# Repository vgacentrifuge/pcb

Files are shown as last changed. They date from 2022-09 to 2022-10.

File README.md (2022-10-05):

# VGA mixer PCB design
This repository contains the research and design work that went into the PCB
for our VGA mixer project in TDT4295 - computer project at NTNU, autumn 2022.

## Initial feasibility study
The [pdf](InitialFeasibilityStudy.pdf) contains the first research, before
the capabilities and requirements were fully fleshed out. In this repo,
we are working on the actual design.

## Project features
The VGA mixer is a device that takes two VGA inputs,
called "background" and "foreground", and outputs a single VGA video stream.

It should support the SVGA resolution 800x600 @ 60Hz and 16-bit color depth.
The colors are stored as (5,6,5)-bit RGB values internally.

On the board there are several buttons and an LCD screen,
allowing you to pick between different **modes**:
 - Showing only the foreground
 - Showing only the background
 - Overlaying with chroma keying appied to the foreground
 - Showing the foreground at 25%, 50% or 75% transparancy
 - Adding the colors (double exposure)

In addition to modes, the foreground can also be **scaled** and **translated**:
 - A button lets you pick between 100%, 50% and 25% size of the foreground.
 - Directional buttons allow you to move the foreground around

Finally, the foreground video input can be replaced by a still image loaded
from an SD card. Chroma keying can still be applied, to create borders or overlays.

TODO: Should we be able to save images, or is having a bank of overlays enough?

The LCD allows the user to orchestrate the modes and options to create quick
transitions, and saving states.

## Implementation overview
Both the background and foreground VGA signals get converted into digial pixel color values.
ADC chips do the conversion, and an FPGA reads the digital data.

The background video signal is never scaled or translated, and can be sent
almost directly out to the output DAC.
The output signal is just a few pixels behind the background.

The foreground gets buffered, either in SRAM or the FPGA's internal block RAM.
When the background signal is passing through the FPGA, it knows which pixel it is processing.
By checking its settings, it will know if and where the foreground framebuffer should be sampled.
Translations and scaling affect how the foreground overlays the background.

Scaling is done by doubling or quadrupling the current pixel coordinate (left shifting).
Translations are done by adding offsets. If the resulting pixel position
is still within the framebuffer bounds, it gets sampled.

Chroma key is handled by looking at the color chanels.
Transparancy is done by averaging the foreground and background layers.
To get 25% foreground, pixel = (fg+(fg<<1) + bg) >> 2, or something similar.
We don't want to do actual division.

User input is handled by an MCU, which is connected to the FPGA via SPI.
The MCU also handles the VGA input data pins, to communicate to our video sources
what resolution we support.

The SD card is also connected to the MCU over another SPI.
We use FAT32 formatted SD-cards, allowing the user to prepare overlays on their computer, saved as bmp.
See [this project here](https://create.arduino.cc/projecthub/SurtrTech/display-bmp-pictures-from-sd-card-on-tft-lcd-shield-f3074c).
The MCU does all file system work and image decoding. The LCD can be used to pick images by file name.
When selected, the foreground input gets ignored, and the FPGA fills the framebuffer with the image instead, sent over SPI.

In general, the MCU takes user input and uses SPI to send a state struct to the FPGA.
This means timed transitions, and switching between saved states, can be orchestrated from there.
Note that the MCU doesn't have enough RAM to store even a single frame.

## Components
This section contains the components we will need to place on the PCB.

### FPGA
We are working with the Artix-7 series, see the [Series Overview](https://docs.xilinx.com/v/u/en-US/ds180_7Series_Overview).

#### Dev-board
The [ARTY A7 development board](https://digilent.com/reference/programmable-logic/arty-a7/reference-manual) has an **ARTIX-7 XC7A35T** which has
 - 33280 logic cells
 - 50 blocks of 36Kib dual port block ram = 1 800Kib
 - 5 clock management tiles (CMTs), each with a phase-locked loop and mixed-mode clock manager
 - Programmable over JTAG or Quad-SPI Flash
 
The dev-board itself contains:
 - 256MB DDR3L with a 16-bit bus @ 667MHz
 - 16MB Quad-SPI Flash
 
#### On PCB
On the PCB we will use the **ARTIX-7 XC7A100T** in FTG256 package, which has already been procured.
 - 4,860 Kib of dual port block ram
 
See the data sheet for it [here](https://docs.xilinx.com/v/u/en-US/ds181_Artix_7_Data_Sheet),
and remember the user guides listed in the pcb lecture.

#### Voltages
The FPGA requires:
 - 1.0V (Vccint & Vccbram)
 - 1.8V (Vccaux)
 - 3.3V (Vcco) The standard signal voltage we use for I/O banks.

They must become ready in order, Vccint and Vccbram can rise together. 
For one bank, Vcco=1.8V, and the datasheet said it's fine to rise it together with Vccaux.

#### Required FPGA support components
In the datasheet they define that certain sets of **decoupling capacitors** should be connected to certain pins.
This is already included in the example schematic from the lecture.
Try to get them close to the pins on the actual PCB.

We also need a **configuration flash chip** on the board,
to program the FPGA on startup. See UG908 Appendix C.
We picked the one from the pcb lecture: [S25FL127SABMFV101](https://www.digikey.no/en/products/detail/cypress-semiconductor-corp/S25FL127SABMFV101/5788556).

#### FPGA's own clock signal
To not completly rely on the MCU's clockout,
The [arty schematic](https://digilent.com/reference/_media/arty:arty_sch.pdf) has and
[ASEM1-100.000MHZ-LC-T](https://no.mouser.com/ProductDetail/ABRACON/ASEM1-100.000MHZ-LC-T?qs=3KFUwL3kAg3Sbz4Re5NI5g%3D%3D), but it's not in stock.

We use the [EC2620TTS-100.000MTR](https://no.mouser.com/ProductDetail/Ecliptek-Abracon/EC2620TTS-100.000M-TR?qs=ZQxglWs2YhXyVb5B6v%252BGOw%3D%3D).

I checked the Xilinx Clocking Wizard, both MMCM and PLL will happily turn 100MHz into 160MHz.

#### Debug connector
The Debug connector from the lecture looks like the **14-pin F JTAG ILA connector**.
See [this website](https://developer.arm.com/documentation/100765/0000/Signal-descriptions/Debug-connectors/14-pin-F-JTAG-ILA-connector).
The pitch is 2mm, yes you read that right.
The component, through hole, can be found here:
[0878311411](https://www.digikey.no/en/products/detail/molex/0878311411/3313107).

See the example setup from the lecture (remember 2x 10k pullups).
However, this website says that pin 6 (TCK) is pulled down on their board,
**why is ours pulled up?** 

### SRAM
We need to calculate the required SRAM size.
With an 800x600=480 000 pixel grid, 16 bit color depth, it makes sense to
use a 512K x 16 bit SRAM. We do however also want to make the SRAM easy to address.

800 pixels of X-coordinate rounds up to 10 bits.
600 pixels of Y-coordinate also rounds up to 10 bits.
A 20 bit address means 2^20 = 1M x 16bit SRAM.

This size would also allow us to support 1024x768 (XGA),
but speed is a bigger issue. XGA has a pixel clock of 15.3ns / pixel.

To get good speed, we have looked at the syncronous 1M x 18b SRAM [CY7C1372KV33-200AXC](https://www.digikey.no/en/products/detail/cypress-semiconductor-corp/CY7C1372KV33-200AXC/5982740)
which supposedly costs 94kr per chip. It takes 3.3V.
With pipelining, the access time becomes 3ns,
with each operation delayed for two cycles.

The number of pins needed becomes:
 - 20 address pins
 - 18 data pins
 - write enable
 - clock
 - chip select
 - output enable

We use chip select to deselect, which when we don't need access.
The deselect is pipelined as well, allowing us to mix it into the operations.

We want to connect output enable to be sure that we never try to
write to th data line while it is being driven.
If we do everything perfectly, The data line is automatically tri-stated by writes,
but we want to be safe.

The rest, like output enable, clock enable, byte enable, advance etc. can all be pulled by the pcb.
This SRAM package does not expose JTAG pins.

### MCU
Available in the lab is the EFM32GG990F1024-BGA112
 - ARM Cortex M3
 - Flash: 1024kB
 - RAM: 128kB
 - USB support
 - ADC: 8 channels, 12 bit
 - DAC: 2 channels, 12 bit
 - SPI: 3
 - I2C: 2
 - GPIO: 87
 - 112 pin BGA package
 
For PCB considerations, see [SiLabs EFM32 AN0002](https://www.silabs.com/documents/public/application-notes/an0002.0-efm32-ezr32-series-0-hardware-design-considerations.pdf).
It includes decoupling capacitors. See Figure 3.1. EFM32 Series 0 Standard Decoupling Example.
Also add the 1 Ohm resistor from Figure 3.3.

#### MCU Debug connector

In the PCB lecture, they use the 2.54mm pitch legacy JTAG.
The debug conenctor is 20-pin header, shown in section 4 of AN0002.

Since we have a gecko with the modern connector, we can use the
modern [Cortex Debug+ETM Connector](https://documentation-service.arm.com/static/5fce6c49e167456a35b36af1).
It has 1.27mm pitch, we pick this through-hole one: [3220-20-0100-00](https://www.digikey.no/en/products/detail/cnc-tech/3220-20-0100-00/3883663).

#### MCU Clock circuit
By using an external crystal, as recommended, we can run the MCU at 48MHz.

<!--
This is simply buying a crystal oscillator.
The [FO7HSCDE48.0-T1](https://www.digikey.no/no/products/detail/fox-electronics/FO7HSCDE48-0-T1/12160237)
is 48MHz, SMD, and with 5mm and 2.5mm between the 4 pins, which at least isn't the smallest oscillator.
The datasheet also has recommended solder pad distance of at least 2.2 mm. Seems doable.
-->

The first chip we bought was in fact not a crystal, but an oscialltor chip using a crystal insternally.
We buy another one instead, see the schematic.

The AN0002 EFM32 hardware design considerations also mentions two capacitors.
The lecture uses 2x 12pF.

The FPGA can take the **clock out** signal from the EMF32GG as a clock input, and use phase-locked loops
to internally run faster clocks at rational multiples of the input.
We should also have a clock circuit on the FPGA side, so that we have two options.

### Connections
We use SPI between MCU and FPGA, and between MCU and SD-card. They can be fully independent.
For our SPI communication, the lecture tells us to add extra wires between the MCU and PCB for safety.

[I2C](https://en.wikipedia.org/wiki/I%C2%B2C) is "open drain", which means we must use pull-up resistors on the lines.
Calculations can be found in this [EFM32GG application note](https://www.silabs.com/documents/public/application-notes/AN0011.pdf).

We use I2C for the LCD, and I2C for the ADCs.
They both seem to like 400kHz, which means a 2kOhm resistor is common.
They both also want to be pulled up to 3.3V.

Between the boards, if we do make two PCBs, we want to connect them.
We can buy e.g. 2 of the 2x8 pin vertical male header per board [3020-16-0200-00](https://www.digikey.no/en/products/detail/cnc-tech/3020-16-0200-00/3441735).
And 2 of the female as well [PPPC082LJBN-RC](https://www.digikey.no/en/products/detail/sullins-connector-solutions/PPPC082LJBN-RC/776019).
These are both through-hole.

### Splitting the MCU and FPGA
We have considered splitting the PCB in half, to separate the MCU from the FPGA.
In practice we will probably not create two PCBs,
since clock lines shouldn't go through pins,
but it would be great to have a PCB that can be used
without the MCU physically on the board.

With SPI, we control the speed ourselves, so we can tune it down until it is stable,
depending on how the wiring is.

The SPI between the MCU and FPGA should have room to solder on a pin header.
The SPI clock is slower than the 48MHz clock-out from the MCU,
which should **not** have a pin header.
We also give the FPGA its own oscillator, to not depend on the MCU clock out.

The SPI lane for the SD card can also have holes for soldering on a pin header if desired.
The I2C buses for the ADCs and LCD screen should have pins,
and the keyboard matrix should have them.

### Power circuit
We base it on the PCB lecture. We need to power up the 1.0V, 1.8V and 3.3V in order.
The MCU and SD card use 3.3V, so does the SRAM.
The ADC uses 1.9V, and HSYNC and VSYNC must be level switched to / from 5V.

**Remember the jumpers** between the power circuit and rest of the board.
We buy a 2x5 male 2.54mm pin header [3020-10-0300-00](https://www.digikey.no/en/products/detail/cnc-tech/3020-10-0300-00/3441727), and
the 2x5 female jumper shunt, [69145-210LF](https://www.digikey.no/en/products/detail/amphenol-cs-fci/69145-210LF/1528094), with 3A rating per pin.

### SD-card & SD-card slot
We want a slot to be able to move the SD-card to and from a computer.
When connected, the MCU communicates via SPI to the card.
In addition to the 4 SPI pins, The SD-card takes a 3.3V VDD and ground.

See for instance [this website](https://www.electroniccircuitsdesign.com/pinout/sd-microsd-card-pinout.html) for pinout on the physical SD and microSD cards.

Note that [this SO-post](https://electronics.stackexchange.com/questions/496357/sd-card-via-spi-pull-up-resistors-or-dedicated-ic)
talks about pull-up resistors on all the data pins, we can do that too.

People seem to disagree, but hooking up a 10k Ohm resistor to each of DAT0-DAT3 and CMD seems good.
Also a 0.1 uF decoupling capacitor between Vcc and GND.

To easily solder, we can buy the [10067847-001RLF](https://www.digikey.no/no/products/detail/amphenol-cs-fci/10067847-001RLF/2283478).
It is full size SD, with solder pins visible

We should buy an SD card as well, the 512MB microSD [5252](https://www.digikey.no/en/products/detail/adafruit-industries-llc/5252/15841478) is cheap,
so buy at least one.

### LCD text output
A cheap 2 row x 16 char width LCD screen is [DFR0555](https://www.digikey.no/no/products/detail/dfrobot/DFR0555/9356340).
It is controlled over I2C.
8-bit address for LCD: 0x7C = 0b 0111 110X
8-bit address for backlight: 0xC0 = 0b 1100 000X
At 87mm x 32mm total, it is quite small. Each char is 2.96mm x 5.56mm.
Mouser doesn't have anything cheaper using I2C, so it's probably a good option.

### Input panel
We need to design a button layout that fits our functionality,
but also allows us to experiment after the PCB design is finalized.

We can use an off the shelf keyboard matrix, and re-label the keys.
Mouser stocks 81 of the 4x4 [3844](https://no.mouser.com/ProductDetail/Adafruit/3844?qs=qSfuJ%252Bfl%2Fd6WS5%252BJGim1hw%3D%3D).

### VGA ports
We need the physical VGA ports, as well as supporting components.
The speed we target is [SVGA 800x600@60Hz](http://tinyvga.com/vga-timing/800x600@60Hz).

The VGA connector itself is [described here](http://www.hardwarebook.info/VGA).
For VGA output we only really need to connect 5 pins, plus ground:
 - red, green, blue color (analog 0-0.7V, 75 Ohm)
 - horizontal sync, vertical sync (5V). See timing chart.

Note: While we are in the "porch" and sync pulse areas of the signal, the color values must all be 0V.
See for example the 2nd [Ben Eater VGA video](https://www.youtube.com/watch?v=uqY3FMuMuRo).

We also might want to connect the 3 DDC2B ports, in case we want to read info about the output monitor.
See the following sections about DAC and VGA Display Data Channel.

For inputs, we need to read those 5 signals, including the analog color signals (using ADCs).
We should also let the video sources get info about our board over I2C. See next sections.

As for the physical VGA ports, there is [L77HDE15SD1CH4FVGA](https://www.digikey.no/no/products/detail/amphenol-icc-commercial-products/L77HDE15SD1CH4FVGA/4888525) on digikey at 15kr a pop. Is has through-hole pins. Buy 9, 3 per PCB.

#### VGA Display Data Channel
The [DDC2B](https://en.wikipedia.org/wiki/Display_Data_Channel#DDC2) standard is an I2C protocol to communicate information about the "monitor" to the video source.

For the output port, we can connect the DDC pins to one of the MCU's I2C ports,
in case we want to read info about the screen.
NOTE: The I2C lines are open drain, and expect to be pulled up to 5V.
We will need a level shifter for the MCU to be able to use the I2C port.

##### VGA DDC level switches
The VGA standard expects 5V I2C over the SDA and SCL lines.
Both when we are slave and master, we want to support this.
Since all other I2C components use 3.3V, we level switch.

[This guide](https://cdn-shop.adafruit.com/datasheets/an97055.pdf)
shows how a single N-channel MOSFET does the trick.
We buy 2 per DDC I2C, 6 per board.
We pick the one they mention that is easiest to solder: [BSN20](https://www.digikey.no/en/products/detail/diodes-incorporated/BSN20-7/2756034).

<!--
For the three DDC channels, we can use one of
[771-LSF0102DCH](https://no.mouser.com/ProductDetail/Nexperia/LSF0102DCH?qs=zW32dvEIR3vhhHCS5E8Gjg%3D%3D)
for each.

If you are curious how open-drain interfaces, like I2C, work through it,
[this datasheet](https://www.ti.com/lit/ds/symlink/lsf0102.pdf?ts=1663455770501)
for a similar device has an example in section 9.2.
-->

#### VGA HSYNC VSYNC Level shifters
They come in at 5V, but must be 3.3V into the ADC.
Same applies to the output VGA, but the other way.
We don't use the DAC's HSYNC and VSYNC ports,
instead letting the FPGA control it.
It would be nice to support 1.8V input, since the rest of video out is at 1.8V.

For each ADC, and for the output, buy one
[771-LSF0102DCH](https://www.digikey.no/no/products/detail/nexperia-usa-inc/LSF0102DCH/13574967).

##### Input VGA ports: I2C EEPROMs
On our VGA inputs, we should respond to I2C read commands, to return 128-256 bytes of read only [Extended Display Identification Data](https://en.wikipedia.org/wiki/Extended_Display_Identification_Data).
See [this page](http://www.hardwarebook.info/VGA_(VESA_DDC)) for specifications.
The VGA DDC uses three pins: I2C data, I2C clock, and DC +5V delivered by the video source.
Our board must respond to the 7-bit I²C address 50h (also known as A0h and A1h in 8-bit).

To save having to use our MCU from needing to be a slave over the VGA ports, we can buy dirt cheep I2C EEPROMSs.
For instance [M24C02-WMN6TP](https://www.digikey.no/no/products/detail/stmicroelectronics/M24C02-WMN6TP/1663568),
in stock at Digikey.no, at 1,7kr a piece. They work at 2.5V - 5.5V, and we use one per VGA input = 6 for 3 boards.

Note: The EEPROMs technically support running on 5V,
and the VGA port has 5V supplied by the graphics card.
The reason we don't want to use it is that the graphics card
expects us to draw < 1mA when the monitor is on.

In DDC, the I2C master will try to read from address 0xA1 = 0b1010 0001.
This is perfect! The EEPROM listens for address 0b1010 XXXX, where
we configure the first 3 X's ourselves. The last bit is 1 for read and 0 for write.

##### I2C EEPROM support components
 - Vcc should be decoupled "usually of the order of 10 nF to 100 nF, close to the Vcc/Vss pins".
 - E0, E1 and E2 should be connected to ground, to listen to the correct address.
 
 - We should create a jumper thing to let the MCU be the programmer, if we ever need to change the EEPROM.
 - It should have 5 pins:
   - Vcc (3.3V)
   - Vss
   - SCL
   - SDA
   - Write enable (just connect to Vss to enable writing)
 
 Opposite to it there should be the same 5 pins comming from one of the MCU's I2C buses,
 e.g. the one used to configure the ADCs.
 
 To make the connector easy, we can use a 3x5 pin header, and have the MCU connected
 to the middle row, and jump either to the left or right.
 See [TSW-105-07-F-T](https://www.digikey.no/en/products/detail/samtec-inc/TSW-105-07-F-T/6692070).

#### Input VGA ADCs
The analog color inputs of each VGA input needs to become digital 6 or 5 bit values.
We can use ADCs with more bit depth than this, and then ignore the least significant bits.

The video ADC we looked at is the 3 channel x 10bit TI [TVP7002PZPR](https://no.mouser.com/ProductDetail/Texas-Instruments/TVP7002PZPR?qs=0OHPnBYoB%2FnBqXV%2Fq5aVXw%3D%3D)

It is configurable over I2C, things like gain, clamp and offset. Also programmable subpixel positioning.
It also has a PLL on the HSYNC, allowing it to generate a pixel clock for the FPGA VGA inputs.
The 40MHz on SVGA is well within the 12-165MHz range.

So: **we need to connect the ADCs to the MCU, to program them**.
Luckily, the chips have one bit of customizable address, so the options are:
 - 0xB8 = 0b10111000
 - 0xBA = 0b10111010
Remember that the last bit is 1 for read and 0 for write.
Notably, neither of these addresses collide with the 0xA0/0xA1 of the VGA DDC,
but you have to remember voltages.

The ADC needs 3.3V and **1.9V**!

The I/O is however 3.3V, so we can connect it to a "normal" FPGA bank.

But: VGA HSYNC and VSYNC are 5V signals. We can **not** pass those into the ADC!
See the HSYNC VSYNC Level shifter section above.

##### ADC support components
See the example setup in the datasheets.

- 1x (=2x) ADC support
     - 3x (=6x) Sync-on-green input disable: 1nF capacitor
     - 7x (=14x) 10nF capacitors for unused analog input
     - 1x (=2x) PLL pump
       - 1x (=2x) Resistor 1.5kOhm
       - 1x (=2x) Capacitor 4.7nF
       - 1x (=2x) Capacitor 0.1uF
   - 1x (=2x) I2C address choice: Resistor 2.2kOhm
   - 3x (=6x) Color inputs
     - 1x (=6x) 75 Ohm resistors
     - 1x (=6x) 0.1 uF capacitors
   - 1x (=2x) VSYNC parallel 1nF capacitor
   - even more stuff, just look at the suggested schematic

#### Output VGA DAC
When outputing analog color data, we don't want to use resistors, as they take space,
and the FPGA outputs are not the best at delivering DC current.

A nice DAC that Mouser stocks is  [THS8136IPHP](https://no.mouser.com/ProductDetail/Texas-Instruments/THS8136IPHP?qs=h8kCHL4kpM5MDIol0WiuLg%3D%3D)
It has 3 10-bit inputs named R, G and B, and 180MS/s.
For 800x600 @ 60Hz, a throughput of at least 40 MSPS is enough.
It takes 3.3V analog, and 1.8V digital.
**This means the FPGA pins delivering VGA out must be 1.8V**.
Luckily, when the Vcco is the same as Vccaux (1.8V), they can be ramped at the same time.

 - 0.1 uF decoupling capacitors near each power pin (3 of them)
 - 0.1 uF capacitors between COMP-AVdd and between VREF-AVss
 - R_FS between FSADJ and AVss. TODO
 - 3x 75 Ohm resistors, for each analog output? TODO

It also has [PCB Layout Guidelines](https://www.ti.com/lit/an/slea077/slea077.pdf?ts=1663284093618).
10x trace width clearance between analog inputs.
Everything close! Resistors, capacitors, analog output port.
TODO: ESD protection on the analog outputs is recommended.

#### Protection
We buy TVS diodes like the [PUSB3AB2DF](https://www.digikey.no/en/products/detail/nexperia-usa-inc/PUSB3AB2DFZ/12325057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).

## Development components
While developing, we want to use some components that might not be part of the finished PCB.

### SD-card reader breakout board
A breakout SD card reader would be great to get the MCU dev-board to do SD-card reading, when developing.
We can make one ourselves by soldering onto the pads of a microSD-SD adapter Håvard has.

Håvard made a shitty one. Done!

### VGA breakout board
It costs a bit, but we can use the [DB15F-VGA-TERM](https://no.mouser.com/ProductDetail/Gravitech/DB15F-VGA-TERM?qs=WZeyYeqMOWcPAs%252BVmUTiLg%3D%3D) from Mouser.

### SRAM breakout board
The SRAM has a 14mm x 20mm 100-pin LQFP package.
We can buy [this board](https://www.digikey.no/no/products/detail/schmartboard,-inc./202-0010-02/9559360)

## Circuit board design
The maunals folder contains the PCB lecture.

For hooking up the FPGA, [this guy](https://www.youtube.com/watch?v=THLdycw9-Vs) from Altium Academy shows
the bare minimum of pins to run an ARTIX-7. Includes flash, voltages and and JTAG.

There is also the [7 Series FPGAs PCB Design Guide](https://docs.xilinx.com/v/u/en-US/ug483_7Series_PCB).

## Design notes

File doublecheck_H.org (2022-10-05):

* TODO
[X] Switch pullups to 2.2k
[X] Add the connectors Paolo expects
[X] 124k -> 120k + 4.7k
[X] 5.49M -> 5.6M
[X] Some LED for the MCU
[X] Add pinouts for power input
[X] Add symbol for LCD
[X] Add #0 to debug pins as well
[X] Change power supply EN pullups to lower resistance (min 1400 Ohm, moved from 100k Ohm to 10k)

* Power circuit
[X] Are all resistors and capacitors the correct values?
[X] Did we calculate correct inductance values?
[X] Is everything connected as supposed to (see pcb lecture)
[X] Use multiple Vias for connecting to ground plane
[X] We do actually use the 16-pin PWP footprint? Yes

[X] The barrel jack has a footprint that works
[X] The barrel jack pin numbers match in datasheet, footprint and schematic
[X] Do all inductors have the correct footprint

* MCU
Datasheet: https://www.silabs.com/documents/public/data-sheets/efm32gg-datasheet.pdf
AN0002 Hardware considerations: https://www.silabs.com/documents/public/application-notes/an0002.0-efm32-ezr32-series-0-hardware-design-considerations.pdf

** Power delivery
[X] Do we provide power to all power inputs (REG, IO and Analog)
[X] All ground pins connected?
[HOPE SO] Are decoupling capacitors placed well?

** Choice of output pins
[X] Make sure all pins are correct in schematic, and support what we want to use them for
NOTE: Make sure you always look at the BGA112 package!

[X] Make sure all features we use are available on the 990
The 990 fully implements the 2x I2C and 3x USART described elsewhere in the datasheet.

[X] Make sure the GPIO pins are available on the 990!
See table 5.20.3 GPIO Pinout Overview.

** Footprint
[X] Are the pins in the correct locations, correct solder pad size and such?

** Debug header
[X] Is it correctly laid out?

** Crystal
Oups, we bought an osciallator, not a crystal.
We should buy a crystal instead, to stay true to the pcb lecture schematic and AN0002.
[X] Are the capacitors correctly placed on the PCB?
[NO] Use KiCADs differental pair routing? No need.
[X] Is the ground plane correctly formed under the crystal?

* I2C
[ ] Buy both 2k and 4.7k pullups in case we need to switch

* Connectors
[X] Check that the 20-pin debug connector is already bought (1.27mm 2x10 male pin header)

For all other pin headers, just buy a fair amount of 1-row and 2-row through hole breakup-able pin headers.
[X] Count the number of 2.54mm pin headers we have per board:
 2-row: (6 PSU disconnect)+(6 PSU breakout)+(4 MCU extra IO)+(5+3+2 FPGA extra IO) = 26 cols
 1-row: (4 MCU extra IO)+((4) MCU-FPGA SPI breakout)+(2+2+2 I2C breakout)+(4 LCU connector)+(8 keypad top) = 26 cols
 Buy enough for 3, and breaking a bunch.
Cheap [[https://www.digikey.no/no/products/detail/sullins-connector-solutions/PRPC040SACN-RC/2776066][1-row x 40]] and [[https://www.digikey.no/no/products/detail/sullins-connector-solutions/PRPC013DFAN-RC/2775401][2-row x 18]]

[X] Buy 8-wide 2.54mm female pin header for easy on and off for the keypad [[https://www.digikey.no/no/products/detail/sullins-connector-solutions/PPTC081LFBN-RC/810147][1-row x 8 female]].

[X] Do we have enough shunts to connect things (6x 5-wide and 25x 1-wide shunts is plenty)

* SD card
[X] Everything connected correctly
[X] Pullup resistors make sense (we have 5, can just de-solder if needed)
[X] Footprint matches the slot we have bought

* LCD screen
[X] Check that the footprint is correct in terms of size and holes, and connection point

* Keyboard matrix
[X] Is the custom footprint correct size? Used a ruler.

* FPGA
[X] Does it get everything it needs from the MCU?

** Config flash
[X] Correct footprint

* SRAM
[X] Footprint correct
[X] All needed pins are connected, either to FPGA, or hardwired correctly.

* DAC
[X] Footprint correct
[X] Matches the suggested schematic
[X] Pin-out pin numbers match
[X] FPGA provides 1.8V digital inputs

* ADC
[X] Footprint correct
[X] Matches suggested schematic (except low pass filter on VSYNC)
[X] pin-out pin numbers match

* VGA
** HSYNC/VSYNC
[X] Level switchers have correct voltages
[X] Level switchers have correct footprint

** DDC
*** EEPROMS
[X] Footprints match (pads are a bit longer and closer than suggested, but should be fine)

*** level switches
[X] Footprints correct for the MOSFETs, both for the input and output VGAs.
[X] Voltages correct on both sides: 3.3V on MCU side, 5V on VGA/EEPROM side

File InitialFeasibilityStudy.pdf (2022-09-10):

## FPGA with Multiple VGA Inputs and Outputs

Research

TDT4295 Computer Project Autumn 2022 Graphics Group

September 9, 2022

Abstract

The goal is to build a board with two video inputs, and two video outputs, and let the user control how the inputs are used to generate outputs. An MCU handles the user interface, while an FPGA accelerates the video input reading and video output writing. It should be able to output effects such as picture-in-picture, split-screen, and chroma keying, independently to both outputs. As an extra piece of functionality, we could allow saving a frame to an SD card, and later use the frame as an input.

## Contents

1 Capabilities we want | 2
2 Components | 3
3 VGA | 4
4 Frame buffers | 6

1

5 External SRAM | 8
6 Bus | 9
7 Clock speeds | 9
8 User interface | 10
9 SD card | 10
10 Conclusion | 10

## 1 Capabilities we want

We want to have two outputs, dubbed output C and D. For each output, we want to be able to configure what to show. We can display one ore more of the following:

- input A
- input B
- Image from SD card

It’s reasonable to set an upper limit of two "layers".

Rendering one layer on top of another is not much fun, so we need ways of combining them.

- Scale the top layer down to 50%, place it somewhere. (Picture-in-picture)
- Scale both layers down to 50%, place them side by side (split screen)
- Chroma key the top layer
- Multiply or add the colors
- Transition from top to bottom layer

2

- Fade from one input to another (similar to transition from top to bottom)

There are lots of options, so we might want to use an LCD screen to pick, and not restrict ourselves to a set of buttons we define on the PCB.

Regarding the picture-in-picture and side-by-side modes, we can hard code in a few placement options (center, corners, edges). Or, we could instead make scaling and translation independent of effects. The scaling could have more options than just 50% size, and translations could be any integer, allowing us to slide layers around, while also applying effects such as chroma key.

Finally, it should be possible to copy the configuration of one output onto the other output. This lets "the director" have a preview before moving the configuration to the other screen.

## 2 Components

- MCU: EMF32GG - Reference Manual on BB

– High Performance 32-bit processor @ up to 48 MHz

– 128 KB RAM

– Up to 90 General Purpose I/O pins

- FPGA: ARTIX-7 XC7A35T (on the dev board). See the Series Overview. (https://docs.xilinx.com/v/u/en-US/ds180_7Series_Overview)

– 33 280 logic cells

– 50 x 36 Kib = 1 800 Kibibits of block RAM (dual-port)

– 250 Max User I/O

– 4 GTP transceivers (maybe useful, not sure)

On the PCBs we make, we use the ARTIX-7 A100

– 135 x 36 Kib = 4 860 Kibibits of block RAM (dual-port)

3

– 300 Max User I/O

- SPI Bus (see Section 6)
- Clock circuit (see Section 7)
- Extra SRAM (see Section 5)
- VGA ports. 2x in and 2x out (see Section 3)
- Power circuit
- Buttons, LEDs and LCD for UI (see Section 8)
- SD card reader (see Section 9)

## 3 VGA

Note: "VGA" often refers to the display hardware used by IBM PS/2, or the 640x480 resolution it had. We care about the actual video signal being sent over the wire.

Using the same connector, a lot of possible display resolutions have been added. See Extended Graphics Array. (https://en.wikipedia.org/wiki/Graphics_display_resolution#Extended_Graphics_Array)

A monitor can communicate with the video source to say what outputs it supports, but our output can ignore this, and just send data over the wire. This is what Ben Eater does in his graphics card. (https://eater.net/vga)

For our VGA inputs, it might be a good idea to implement the monitor description protocol, such that the devices providing inputs give us video in our native frame buffer size, with known timings.

VGA has analog color signals, so we must somehow make it digital, process it, and turn it back into analog output.

4

### 3.1 Analog-to-Digital

The ARTIX-7 FPGA contains a 12-bit Analog-to-digital converter (called XADC). It can take up to 17 analog inputs, by multiplexing. We only need 6 (2 inputs·3 colors). However, the ADC has a bandwidth of 1 million samples per second. That is not enough.

The proper ADC to use would be a dedicated one. For instance TI’s TVP7002. (https://www.ti.com/product/TVP7002) That should support as high as 1080p, because the ADC supports higher than the 148.5 MHz necessary for 1080p@60.

### 3.2 Digital-to-Analog

Good resources have been written on making DACs. Eli Gladman designed the rgbs888 (http://eli.gladman.cc/blog/2020/07/21/raspberry-pi-rgbs-output.html) which uses an R-2R DAC. (https://www.tek.com/en/blog/tutorial-digital-analog-conversion-r-2r-dac) No matter what bit depth we choose, this is probably a good design. Ben Eater (https://eater.net/vga) also used resistors to create a DAC for VGA.

The VGA color outputs should be between 0V - 0.7V for full dark to full brightness. This range is easy to achieve using R-2R.

If we want to use a proper DAC, which simplifies all of the analog sections and should reduce size, we can use e.g. TI’s THS8136. (https://www.ti.com/product/THS8136) The advantage is it should make our life simpler, but we can’t cheat by changing resistor values.

### 3.3 VGA timings

By outputting signals on the red, green and blue channels, as well as h_sync and v_sync, we can send an image to the monitor. To pick a resolution and get the timings required, see VGA timing. (http://www.tinyvga.com/vga-timing) There is also this blog article here (https://projectf.io/posts/video-timings-vga-720p-1080p/) that details the most common resolutions up to 1080p.

A lower bound is the standard VGA 640 x 480 @ 60Hz. The website tells us that this requires a pixel frequency of 25.175 MHz. This means two things: The VGA part of the FPGA should have a clock speed divisible by this, and we have ∼ 39.72 ns to process each pixel.

Another, slightly higher fidelity option in SVGA, 800x600 @ 60Hz. The nice thing about this is the pixel frequency of 40 MHz. This gives exactly 25 ns of pixel time.

5

The higher resolutions use HDMI, which would save us the use of ADCs and DACs, but have other implementation challenges. Also note that 720p and 1080p have pixel timings of respectively 13.5 ns and 6.7 ns.

## 4 Frame buffers

We need to pick a size for our inputs. It should be standard, and not too big. One concern is the size of RAM. The FPGA dev board has a smaller built in RAM than the FPGA we will use on the PCB, but we can also add external SRAM to get more space.

Another concern is the throughput, both over the VGA ports, and to/from the memory. We need to pick a framebuffer size small enough to get all the data in and out every frame.

How many bits of color depth we store will affect both memory requirements and how advanced the output DAC needs to be. Depending on the resolution, we have different amounts of time to process each pixel.

### 4.1 What needs to be buffered?

At least one input signal must be buffered, since the inputs won’t be in phase. To be able to translate both inputs, we must buffer them both.

Finally, the image saving / displaying might require storing the image in RAM, depending on the speed of the SD card operations. If we want to save on chips, we can require that loaded images always replace one of the input VGAs, thus repurposing the same frame buffer.

### 4.2 Frame buffer sizes

As a lower bound, we can try using the original VGA mode. 640x480 pixels, with an 24-bit color depth, gives a size of

640 · 480 ·

3 colors
pixel ·

1 byte
color = 900KiB

By reducing the color depth, which is a sensible thing to do, we can get more room.

6

By giving each channel 5 bits, a pixel fits in 2 bytes. The green channel can even get 6! This gives a memory usage of

640 · 480 ·

2 bytes
pixel = 600KiB

To give an idea of what a 640x480 image with 16-bit color depth looks like, see Figure 1. For the same images with a naive 8-bit color palette, see Figure 2

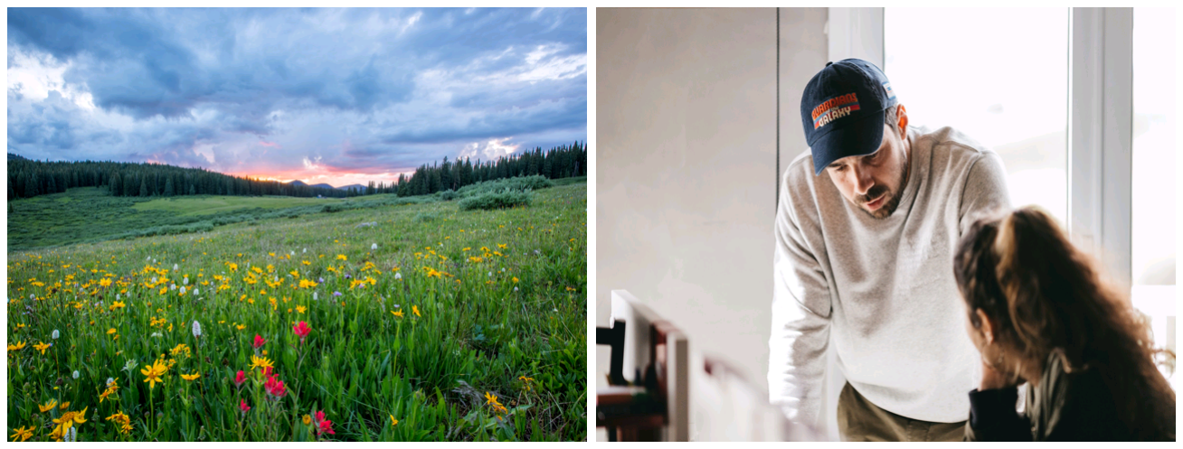
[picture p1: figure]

Figure 1: 640x480 with (5,6,5)-bit color depth. Images taken from Unsplash.

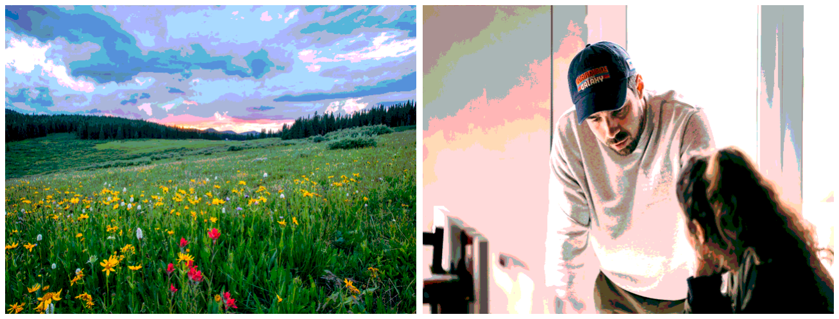
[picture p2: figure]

Figure 2: 640x480 with (2,3,3)-bit color depth. Images taken from Unsplash.

For reference, a 800 x 600 image with 16-bit colors takes up 937.5 KiB

7

If we want to design for the very highest resolution we could go for, 1080p with 24b colour is 6075 KiB. At 60Hz that is a throughput of ∼ 356 MiB/s.

## 5 External SRAM

As the framebuffer section showed, a single framebuffer will be at least 600KiB. The onboard block RAM in the dev board FPGA is 1800Kib = 225KiB. The final FPGA has 607 KiB of RAM, which is just enough for one framebuffer. It thus seems sensible to add an external SRAM chip. There are guides (https://www.hackster.io/salvador-canas/a-practical-introduction-to-sram-memories-using-an-fpga-i-3f3992) that show examples of using SRAM from Verilog on an FPGA.

It’s worth noting that the async SRAM they used doesn’t take a clock signal. Instead it takes some time between the address is stable, and the data is ready to be read.

Table 1 shows how much time you have per pixel, and the minimum throughput required to read the buffer 60 times a second.

Resolution | Pixel time Min. throughput per buffer
VGA 640 x 480 8b | 39.72 ns | 140.6 Mib/s
VGA 640 x 480 16b | 39.72 ns | 281.3 Mib/s
SVGA 800 x 600 16b | 25ns | 439.5 Mib/s
720p 24b | 13.4ns | 1.27 Gib/s
1080p 24b | 6.7ns | 2.85 Gib/s

Table 1: Pixel times and required througput to output different frame buffers

Looking at Mouser, if we use the IS64WV51216EEBLL-10CT2LA3 (https://no.mouser.com/datasheet/2/198/61-64WV51216EEALL-BLL-1275459.pdf) 512Ki x 16bits SRAM with 10ns read cycle, we can fit 3 read/write operations per pixel in the VGA output. Recall that a 640x480 @ 60Hz gives us ∼ 39.72 ns per pixel.

SVGA, aka 800x600, only gives us 25 ns per pixel. We tried looking for SRAM chips with 32 bit data buses, which would allow us to read/write two pixels per access. One such chip is GS881Z32CGD-150I, (https://no.mouser.com/ProductDetail/GSI-Technology/GS881Z32CGD-150I) costing 160kr. With 256K 32-bit rows, it can store an entire SVGA frame buffer. By storing pixels two at a time, we get 50 ns per two pixels. This SRAM is synchronous, which means we give it a clock. That clock can have a period down to 7.5ns. It should then be very safe to operate with an e.g. 10ns clock.

| 8

We will need to read the SRAM data sheet thoroughly, to make sure we can actually access the RAM like we think. The data is input and output one cycle after the address!

### 5.1 What about DRAM?

DRAM requires more work, such as a clock and refreshing, but it can also go fast for cheap.

The Arty dev boards we have do include a DDR3 chip and it looks like it shouldn’t be tremendously difficult to use if we use Xilinx’s IP. Digilent has a guide here. (https://digilent.com/reference/programmable-logic/arty-a7/reference-manual#ddr3l) However, the throughput of this DDR3 is 667Mbps, which is enough to read and write to one 640x480 16b frame buffer, but not two.

On Mouser we find DRAM chips like the IS42S16100H-6TLI (https://no.mouser.com/ProductDetail/ISSI/IS42S16100H-6TLI) for only 19kr, which has room for 1Mi 16b pixels, and an access time of 6ns. Its access patterns are however much more complicated, with burst reads and rowns and columns and stuff.

## 6 Bus

The SPI interface is a synchronous serial databus. It has a clock signal from the master, and full duplex data lines. We can also add slave select lines to connect several components. The MCU will be the master, with the FPGA, SD card and LCD as slaves. SD cards are already built around SPI, so that’s perfect.

## 7 Clock speeds

The Cortex-M3 in the MCU can go up to 48MHz.

Depending on the length of the longest critical path in our FPGA design, we can run it at 100MHz - 300MHz, was a ballpark range provided by the TA. We could try to pipeline the operations to get it even faster.

We will need to handle a number of FIFOs on the FPGA, because we have a number of clock domains. VGA runs at wildly different frequencies depending on resolution and framerate and the FPGA logic will have some (quite high) frequency. Then, each VGA output controller will also need to run in a separate domain, and for the

9

various external memories those will run at a much higher frequency than the FPGA logic because otherwise the memories’ throughput can’t be fully utilised. Fortunately however we can generate all the clocks on the FPGA side off a single clock generator circuit and PLLs.

A final thing that affects clock speeds is the amount of electromagnetic interference on the PCB. See this article (https://www.mclpcb.com/blog/pcb-electromagnetic-issues/) for tips to reduce EMI on our PCB.

## 8 User interface

The exact interface will have to be based on the features we will end up supporting, but we will of course need to pick a UI before designing the PCB.

## 9 SD card

Read about SD card over SPI here. (https://www.renesas.com/eu/en/document/apn/sd-memory-card-interface-using-spi)

## 10 Conclusion

Considering the different options for video resolution, color depth, frame buffer stor-age and processing, we can try to come up with a design we think might work.

10

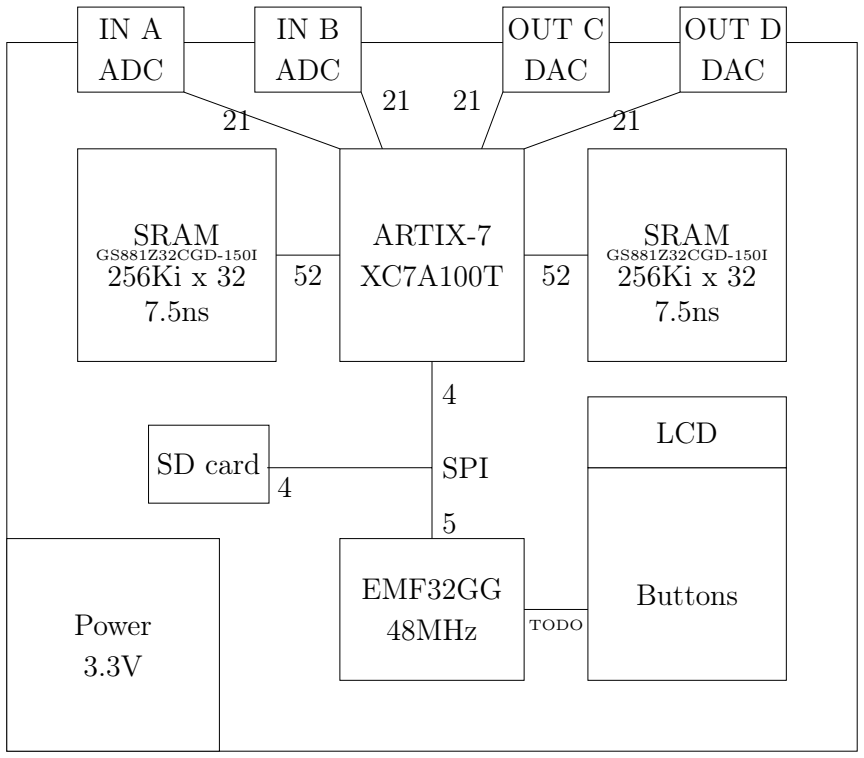
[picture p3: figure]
IN A ADC; IN B ADC; OUT C DAC; OUT D DAC; ARTIX-7 XC7A100T; SRAM GS881Z32CGD-150I 256Ki x 32 7.5ns; EMF32GG 48MHz; SD card; Buttons; LCD; Power 3.3V; SPI; TODO

Figure 3: Overview of which components are connected, and how many pins the connec-tions take

11

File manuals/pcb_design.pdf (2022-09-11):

Department of Computer Science, NTNU

# TDT4295 COMPUTER DESIGN PROJECT

## PCB Layout

Asbjørn Djupdal

2022-09-09

## From Idea to PCB

The road from...
- ...a rough idea of your system
- ...to a finished circuit board

1

## Todays Lecture

Workflow

EFM32

Artix FPGA

Power Supply

Final Tips

2

## Typical Workflow

### 1. Decide on functionality 2. Decide on the main components 3. Draw schematics 4. Draw the PCB layout

3

## Typical Workflow

### 1. Decide on functionality 2. Decide on the main components 3. Draw schematics 4. Draw the PCB layout

4

## Functionality

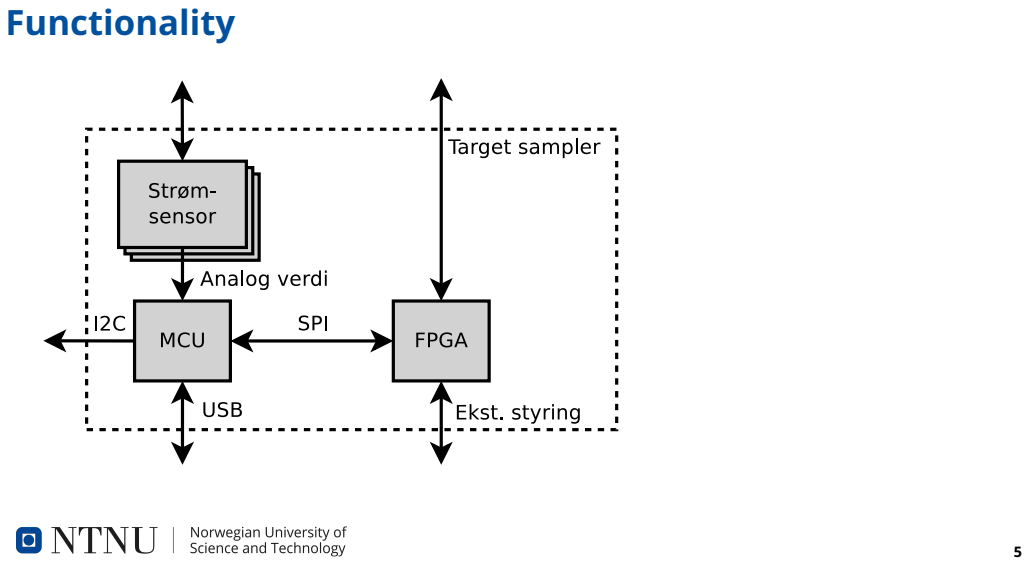
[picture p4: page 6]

## Typical Workflow

### 1. Decide on functionality 2. Decide on the main components 3. Draw schematics 4. Draw the PCB layout

6

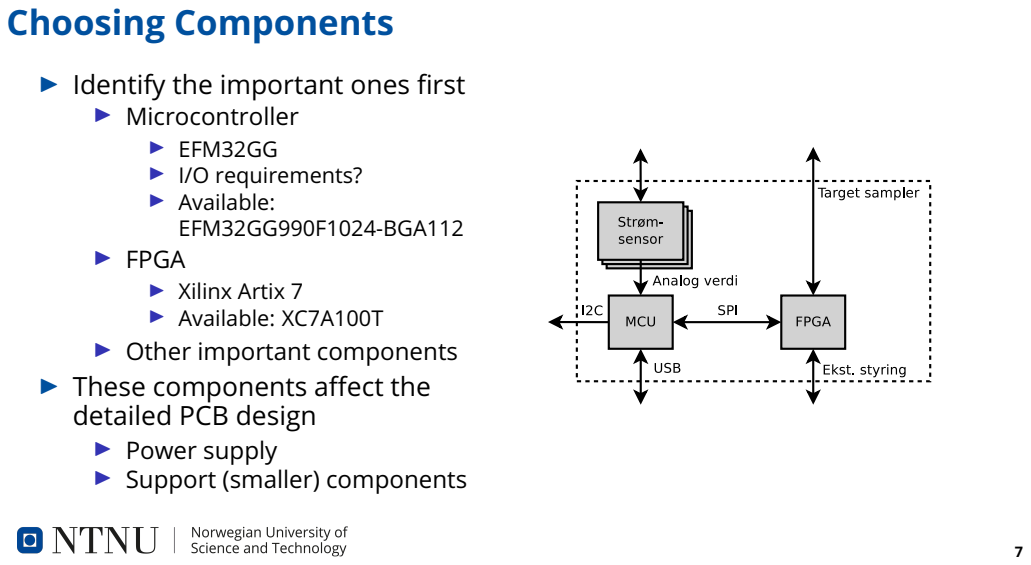
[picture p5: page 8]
EFM32GG990F1024-BGA112

Choosing Components ▶ Identify the important ones first ▶ Microcontroller ▶ EFM32GG ▶ I/O requirements? ▶ Available:

▶ FPGA ▶ Xilinx Artix 7 ▶ Available: XC7A100T ▶ Other important components

▶ These components affect the
detailed PCB design ▶ Power supply ▶ Support (smaller) components

## Choosing Components

Choose components that are easy to use:
- Some components require complex support circuits and / or complicated PCB layout
- Some components can be difficult to drive from software
- Are there drivers available you can use?
- Make sure that your components are compatible with each other
- Voltage levels: Try to keep to 3.3V for all signals on the PCB
- Communication standards (SPI/I2C/...)
- Read and understand the datasheets

8

## Choosing Components

Choose components that are easy to solder:
- The same component is often available in different packages
- Easy to solder by hand:
- QFP
- SOIC / *SOP etc
- SOT
- Require solder oven:
- BGA
- QFN
- Choose a large pitch (distance between pins)
- Preferably 0.5mm or more (1mm for BGA)
- Resistors / capacitors etc:
- Follow the datasheets
- If not specified, choose 0805 or 1206 as standard
- Avoid smaller than 0603

9

## Choosing Components

Choose components you can get:
- Check availability on our main suppliers
- no.farnell.com
- digikey.no
- You do not have time to wait for months for components
- Send us your shopping lists as soon as possible
- You don’t have to order everything at once
- Order enough for at least 3 boards

10

## Typical Workflow

### 1. Decide on functionality 2. Decide on the main components 3. Draw schematics 4. Draw the PCB layout

11

## Schematics

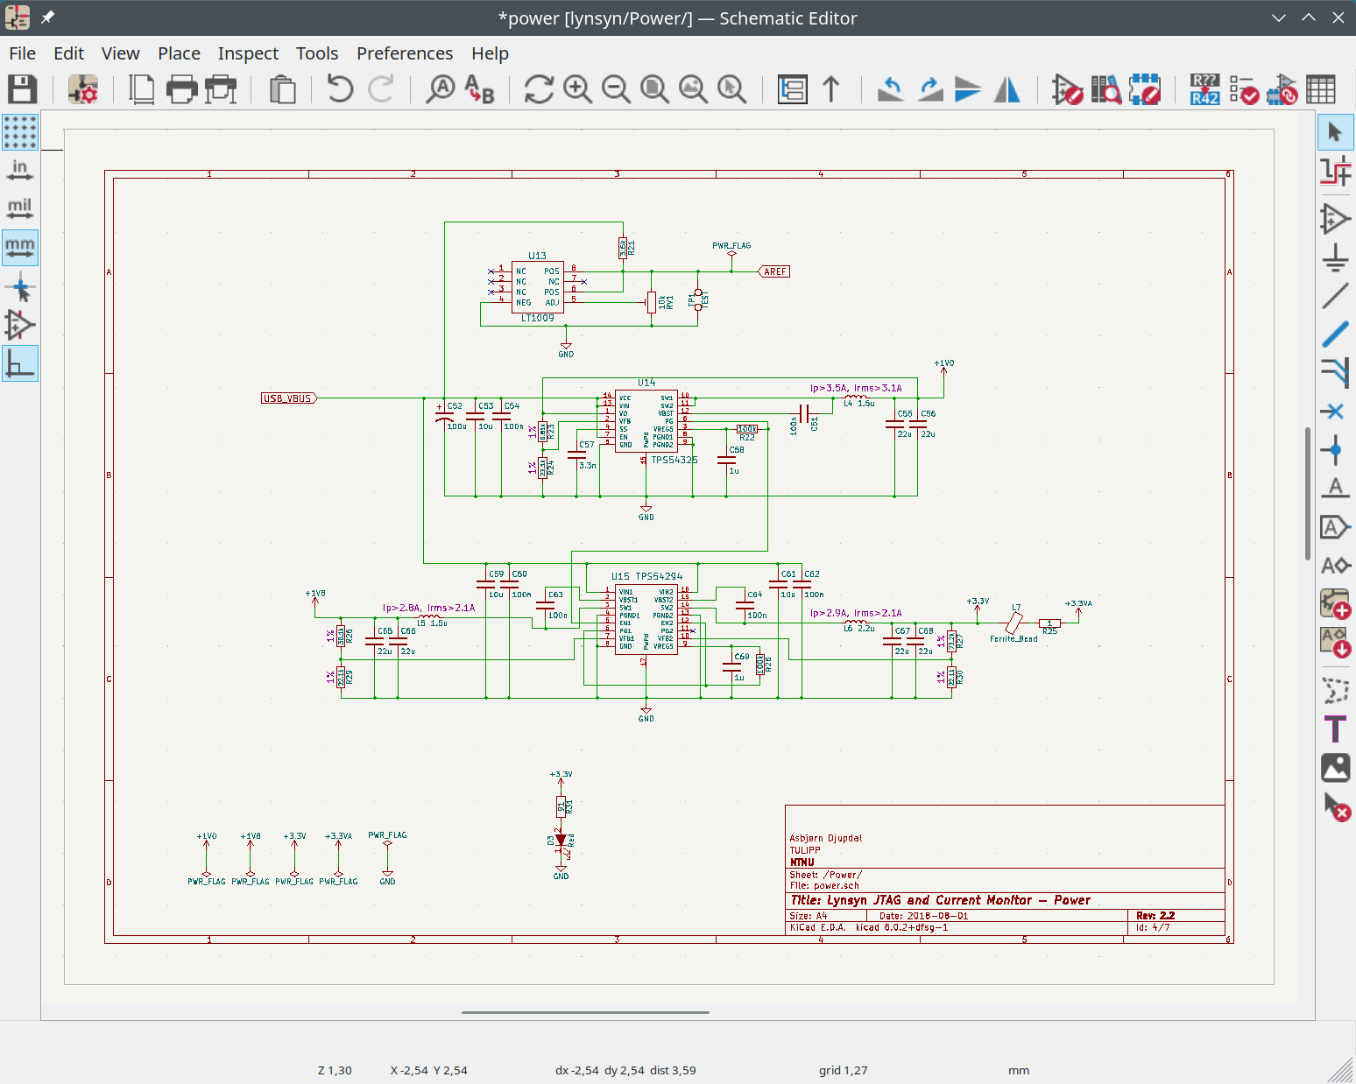
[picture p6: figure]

- KiCAD
- Drawing of your system
- Specifies how components are connected
- Does not show anything about physical placement, trace width etc.
- This is the most important part of the PCB design
- The schematic netlist can then be transferred to the PCB tool

12

## Schematics

- Follow the examples in the datasheets
- Almost all components have an example that can be modified to your needs
- Use hierarchical boxes / schematics
- Microcontroller
- FPGA
- Power supply
- Run ERC (Electrical Rules Checker) before transferring netlist to the PCB tool

13

## Symbols

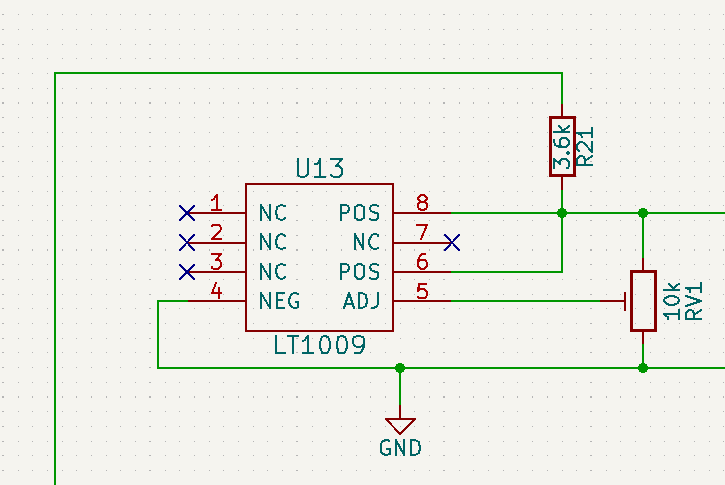
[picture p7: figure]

- Symbols represent a PCB
component in the schematic tool
- KiCAD has symbols for many components
- You probably have to make some
- Make sure the pin numbering is correct

14

## Decoupling Capacitors

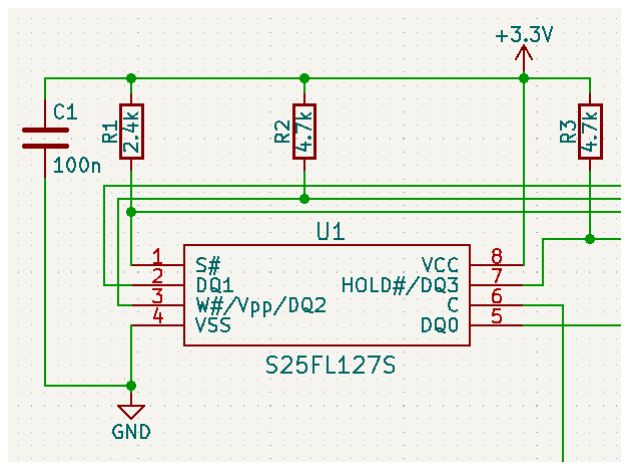
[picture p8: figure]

- Most chips need one or more decoupling capacitors
- Keeps supply voltage (VCC) constant
- Placed close to the VCC pins (on the PCB, in the schematic it does not matter)
- Copy the datasheet!

15

## Design for Testing and Bugfixing

- Add test points for connecting measurement equipment
- But not on fast signals
- Route some spare GPIO pins out on pin headers
- Flexibility for expansion / backup solutions
- Both from FPGA and the microcontroller
- Add redundancy
- Want HDMI output? Add VGA also
- Want SPI bus between FPGA and MCU? Add some extra wires

16

## Connect Schematic Symbol to Footprint

- Each symbol must be assigned a footprint
- The physical drawing of the component
- Soldering pads
- Mounting holes
- Text printed on the PCB
- KiCAD has most standard footprints
- If you have to draw your own:
- Be accurate
- Do not mirror the pins
- Follow the datasheets
- Print your footprint on paper and check

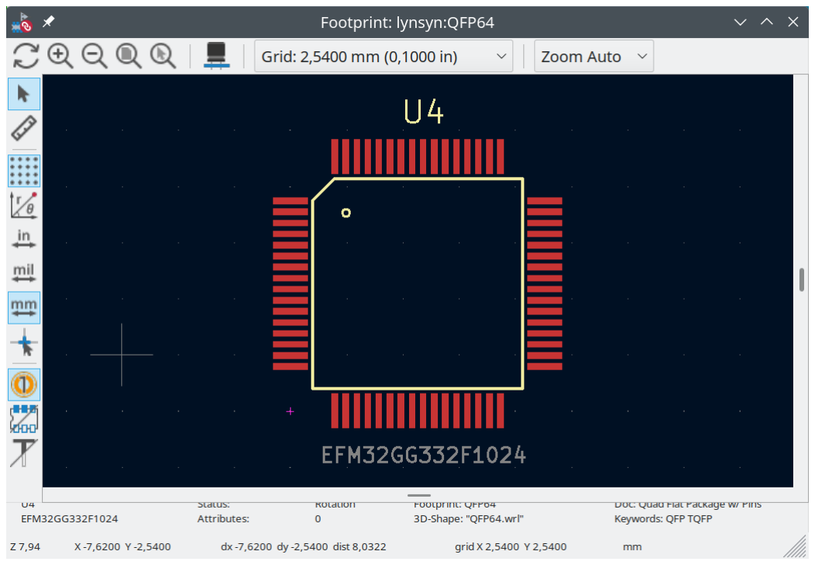
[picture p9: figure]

17

## Typical Workflow

### 1. Decide on functionality 2. Decide on the main components 3. Draw schematics 4. Draw the PCB layout

18

## PCB Layout

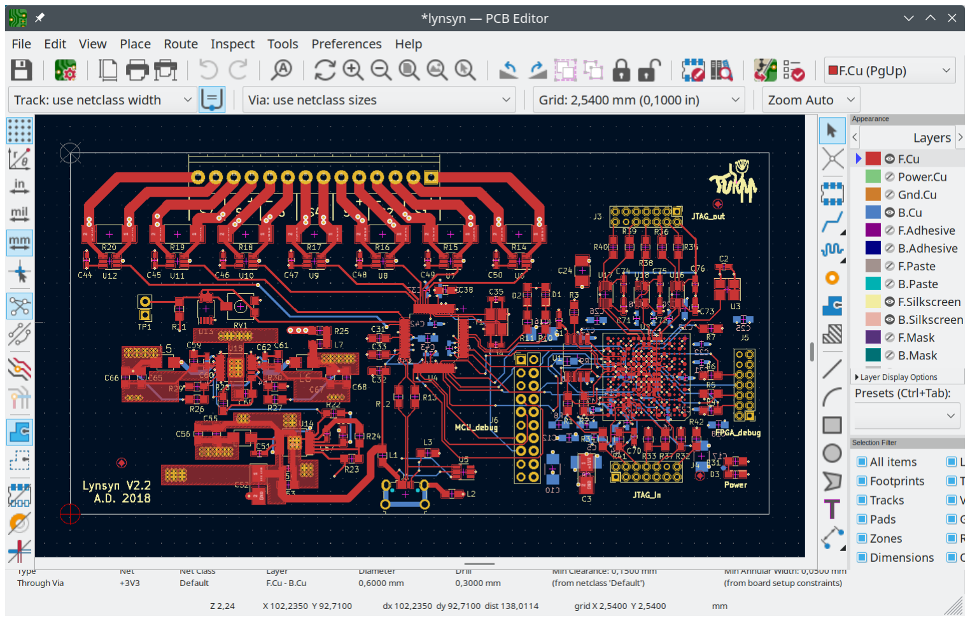
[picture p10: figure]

- KiCAD
- Physical layout of the PCB
- Place components
- Routing: Draw the metal traces between component pins
- Uses the netlist from the schematic to make sure everything is correctly connected

19

## PCB: Setup – Number of Layers

A PCB has several layers with copper traces

- Use 4–8 layers
- One internal ground layer
- At least one internal VCC layer
- At least two signal layers (top and bottom)
- Number of layers:
- Few layers: Cheap
- Many layers: Easyer to route
- FPGA is difficult to route with only 4 layers

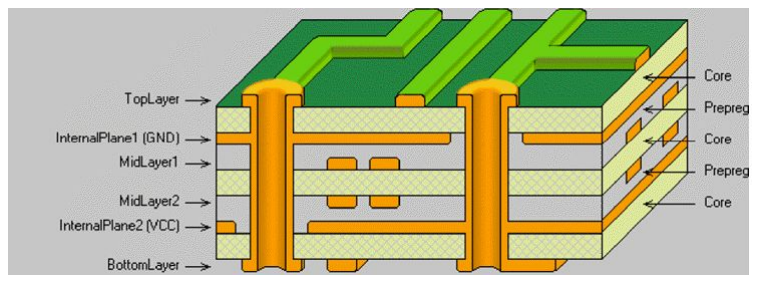
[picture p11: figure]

(allaboutcircuits.com)

20

## PCB: Setup – Design Rules

The rules you have to follow to make your PCB possible to produce
- KiCAD lets you specify the rules, and then enforces you to follow them
- Get information from the factory (https://www.elprint.no/kapabilitet)
or use the following:
- Clearance: 0,125 mm
- Track width: 0,125 mm
- Via dia: 0,6 mm
- Via is a connection between one layer to another
- Via drill: 0,3 mm
- Tighter design rules can also be fabricated, but remember that small is expensive.

21

## PCB: Placement of Components

You are now ready to start laying out the PCB
- Place all components manually
- Then draw the edges of your board
- Don’t make the board too small
- Think about placement and rotation
- Important for how easy routing is later
- Do not place components too close to other components
- Difficult routing and difficult soldering
- Group your components according to your schematics
- Follow any recommendations from the dataseheets

22

## PCB: Routing

- I recommend manual routing
- Autorouter does not produce a good result
- Don’t use mimimum trace width, unless necessary
- Use one standard width for signal traces, another thicker width for power traces
- Don’t use “buried” or “blind” vias. Only normal through-hole vias
- Don’t put a via in a solder pad

23

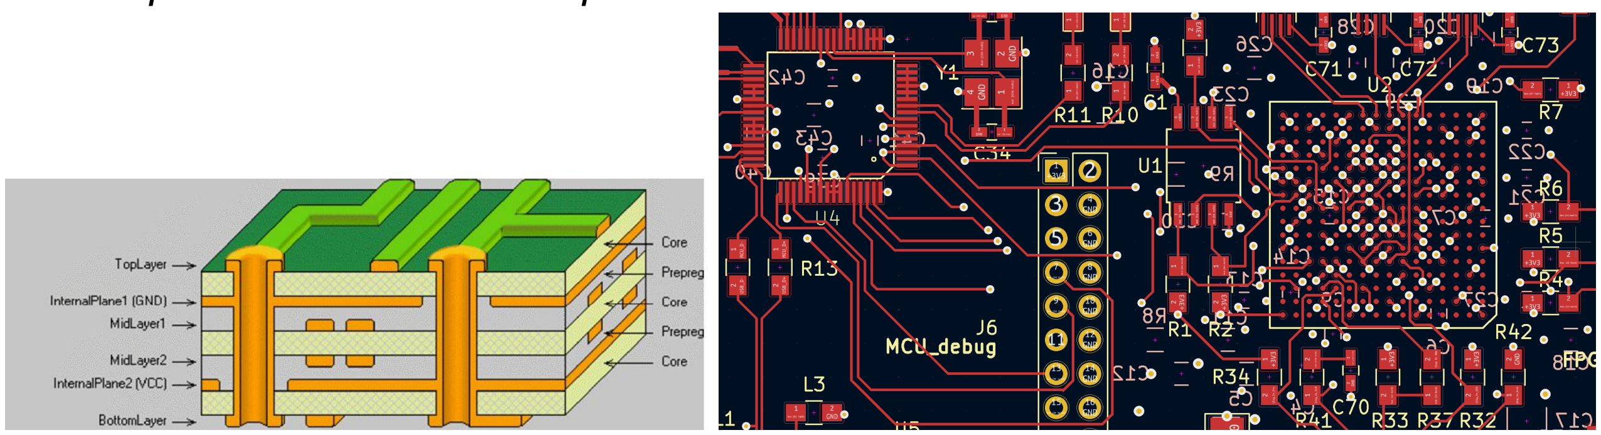
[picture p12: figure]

## PCB: Signal Integrity

- Wire traces on the PCB are not perfect
- Act as transmission lines at high frequencies
- Has an impedance
- May interfere with close-by traces
- Some designs need a specific impedance and/or length matching
- DDR memory
- RF circuits
- Advice: Avoid if you can
- If not, read up on it and discuss with me
- Differential pairs (e.g. USB) should be routed correctly
- Use KiCAD differential pair router
- Keep high speed lines short
- Place crystals and oscillators close to the chips they feed
- Don’t route sensitive signals through connectors or via pin headers

24

## PCB: Analog and Digital

- For minimum amount of noise: Separate analog part of PCB from digital part
- Put the analog part towards an edge of the PCB
- Not between power supply and digital part
- Normal to have separate VCC for the analog circuits (see EFM32 AN0002 for an example on isolating the analog VCC)
- Big and complex topic
- Don’t speed too much time thinking about it
- Audio will work anyways (possibly with worse sound quality), even if you ignore all analog advices

25

## PCB: Finalization

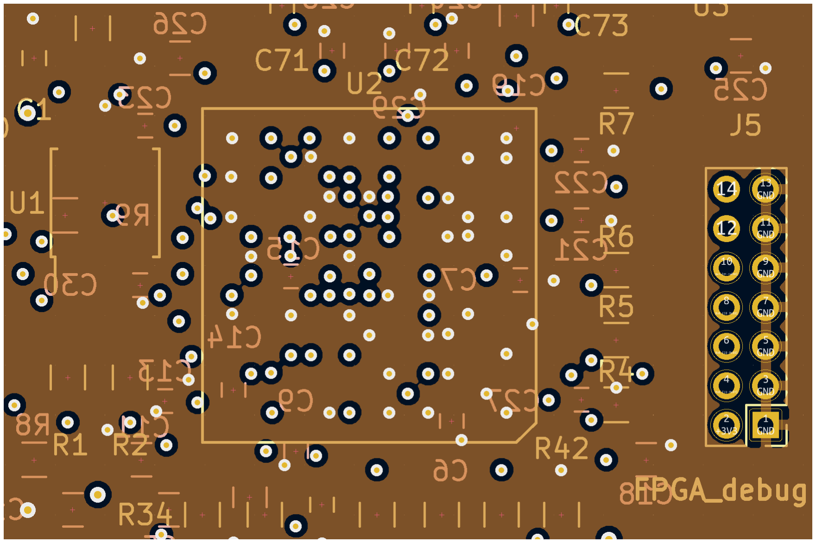
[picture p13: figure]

- Fill all planes
- Gnd and VCC layers are “planes”
- Check that your vias have not damaged any of your power planes
- Run DRC (Design Rules Checker)
- Print to paper and check that:
- Components fit physically
- There is enough space for the soldering iron

26

## EFM32GG

- Easy to use
- Power supply: 3.3V
- Clock: Can use an internal oscillator, or external crystal
- Recommend 48MHz external crystal
- Exist in many variants (parts): Choose the part with the properties you need
- I/O
- Flash
- Remember to include the debug connector
- Relevant documents for PCB:
- SiLabs EFM32 AN0002 (Hardware Design Considerations)
- Prefer package QFP64

27

## EFM32GG – Availability

- Many parts are difficult to get these days
- Available in our lab: EFM32GG990F1024-BGA112
- ARM Cortex M3
- Flash: 1024kB
- RAM: 128kB
- USB support
- ADC: 8 channels, 12 bit
- DAC: 2 channels, 12 bit
- SPI: 3
- I2C: 2
- GPIO: 87
- 112 pin BGA package

28

## EFM32GG

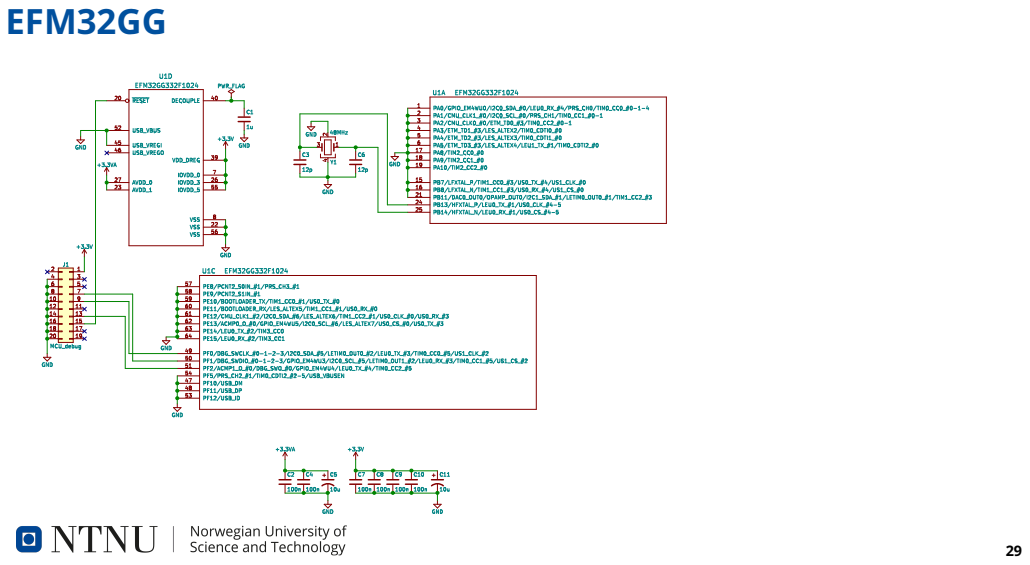
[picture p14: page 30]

## Xilinx Artix 7 FPGA

- Complex chip
- Needs a lot of support circuits on the PCB
- Complex power supply
- Lots of decoupling capacitors
- Need a flash chip for the configuration
- JTAG connector
- Preferably choose the FTG256 package
- Available in the lab: Artix 100T (FTG256)

30

## Artix 7 – Relevant Documents

- UG483: 7 Series FPGAs PCB Design Guide
- Information about decoupling capacitors
- XAPP586: Using SPI Flash with 7 Series FPGAs
- How to connect the Flash chip and JTAG connector
- UG908: Vivado Design Suite User Guide
- Appendix C has a list of supported Flash chips
- Other documents:
- UG470: 7 Series FPGAs Configuration
- More about JTAG and configuration
- XAPP427: Implementation and Solder Reflow Guidelines for Pb-Free Packages
- Soldering of Xilinx BGA chips

31

## Artix 7 – Decoupling Capacitors

- Needs lots of decoupling capacitors
- Sizes, number and max distance to chip is specified in UG483
- One possibility is to place these on the bottom of the PCB

32

## Artix 7 – Flash

- FPGA needs a separate Flash chip for its configuration
- Choose one which is compatible:
- Choose from appendix C in UG908
- Copy schematic from XAPP586

33

## Artix 7 – JTAG and Reset

- Connect as in XAPP586
- Add 10k pullup resistor on TMS and TCK to avoid problems when JTAG cable is disconnected
- A pullup resistor is a resistor connected to VCC. Makes sure the line is high if nothing else drives it low

34

## Artix 7

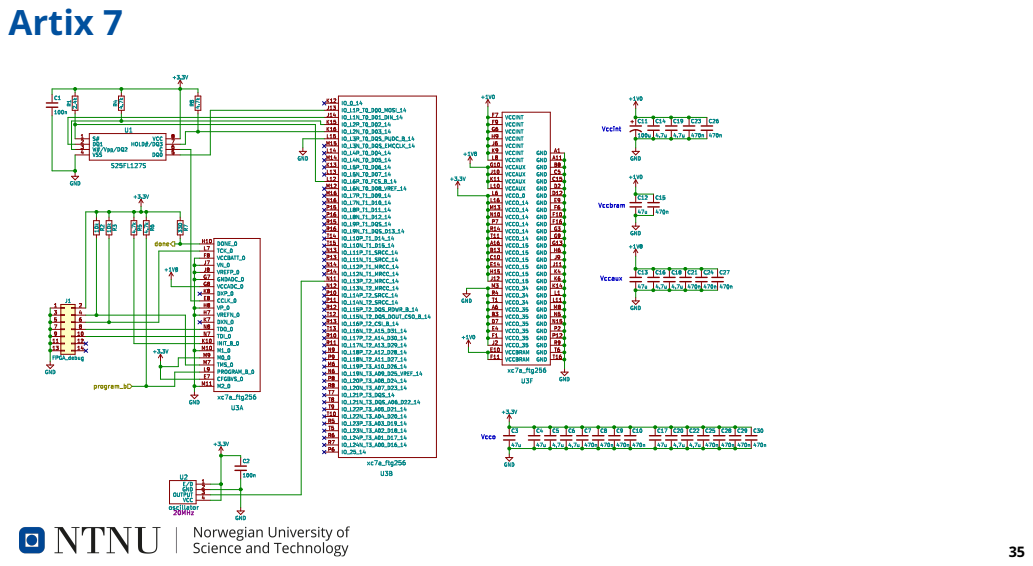
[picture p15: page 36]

## Power Supply

- MCU needs 1 voltage: 3.3V
- FPGA needs 3 voltages: 1.0V, 1.8V, 3.3V
- Must be switched on in the correct sequence
- Switching converter (buck converter) or linear?
- Switching is more efficient
- Linear is easier to use

36

## Power Supply Schematics

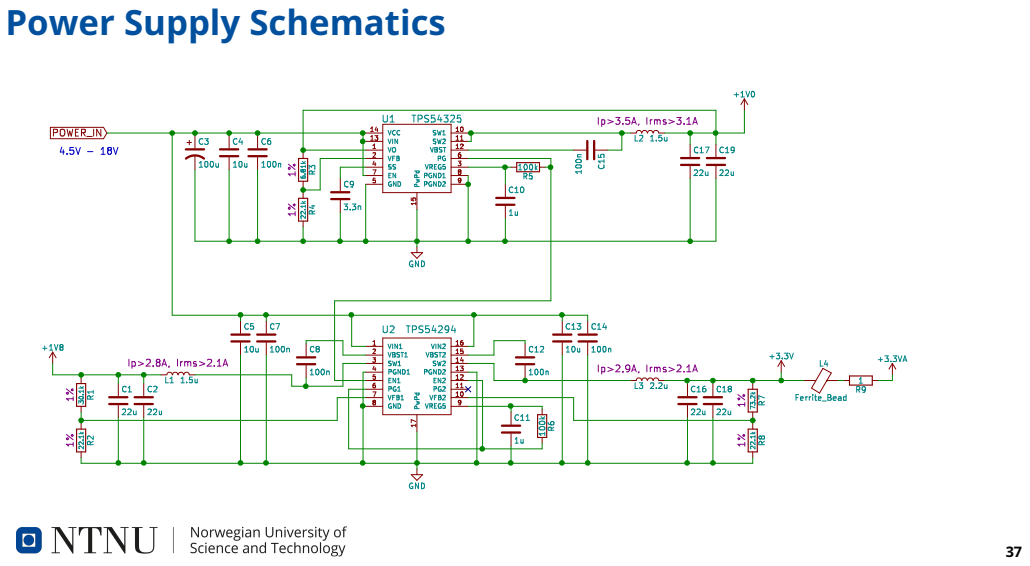
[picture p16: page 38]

## Power Supply Advice

- Power supply is complex, and critical
- Incorrect voltages damages the rest of your components
- Have a backup plan
- Use jumpers to connect the voltages to the rest of the board
- Allows you to disconnect a faulty power supply and add a lab supply

38

## TPS54294 Layout

39

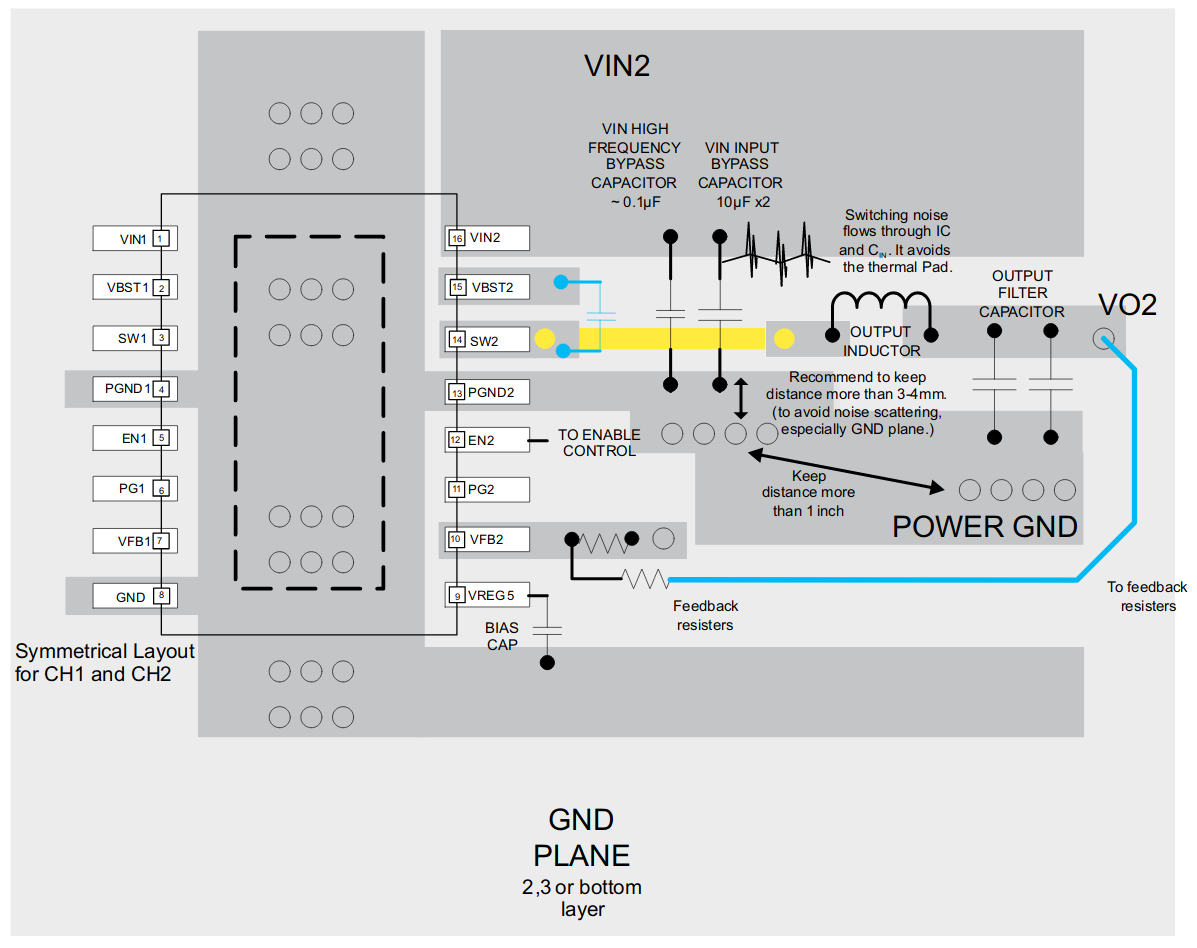
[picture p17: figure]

## Final Tips

- Start with schematics for the power supply, FPGA and MCU
- Adapt schematics from this lecture to your needs
- Then add other chips and components to your schematics
- Read the datasheet for info about decoupling and usage
- Add the support components as you go
- When using git: Don’t merge your KiCAD files
- One person per schematic file
- Check these slides regularly

40

## Delivery

Send me the complete design by the end of the month
- Complete functionality
- Passes all tests

41

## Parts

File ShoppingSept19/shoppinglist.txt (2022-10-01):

Multipliers in this document are all per board.

Already bought:
 - FPGA: ARTIX-7 XC7A100T in FTG256
 - MCU: EFM32GG990F1024-BGA112
 - Switching power supply chips
 - A bunch of 2.54mm male pin headers, both single and double.

Development things already bought:
 - Homemade SD card "breakout board"
 - VGA Pmod output, we might use for testing

To buy, per PCB:
 - FPGA [Already bought]
   - decoupling capacitors and resistors
   - Clock oscillator: EC2620TTS-100.000M TR [Mouser Listed OK]
   - config flash: S25FL127SABMFV101 [DigiKey Listed OK]
   - JTAG connector 2mm 14-pin: 0878311411 [DigiKey Listed OK]
 - 5x (in total) SRAM: CY7C1372KV33-200AXC [DigiKey Listed OK]
 - MCU [Already bought]
   - decoupling capacitors and resistors
   - MCU programming connector, 20-pin 1.27mm: 3220-20-0100-00 [DigiKey Listed OK]
   - MCU Crystal Oscillator: FO7HSCDE48.0-T1 [Digikey Listed OK]
     - 2x decoupling capacitor 0.01 uF / 12pF
 - General connectors [just pin headers?]
 - Power circuit resistors and capacitors
   - Power circuit jumpers [Use 2.54mm header pins]
 - SD-card slot: 10067847-001RLF [DigiKey Listed OK]
   - 0.1 uF decoupling capacitor
   - 5x 10k Ohm pull up resistors
 - 1x (in total) microSD 512MB card: Adafruit 5252 [DigiKey Listed OK]
 - LCD text screen: DFR0555 [Digikey Listed OK]
 - Keyboard matrix: Adafruit 3844 [Mouser Listed OK]
 - 3x VGA ports: L77HDE15SD1CH4FVGA [DigiKey Listed OK]
 - 6x I2C Level shift MOSFETs: BSN20-7 [DigiKey Listed OK]
 - 6x Level shifter for H/VSYNC: LSF0102DCH [DigiKey Listed OK]
 - 2x VGA DDC I2C EEPROMs: M24C02-WMN6TP [DigiKey Listed OK]
 - 2x 3-channel 10-bit ADC: TVP7002PZPR [Mouser Listed OK]
  - A bunch of capacitors and resistors
 - VGA Output DAC: THS8136IPHP [Mouser Listed OK]
  - 3x 75 Ohm resistors
  - 1x R_FS reference resistor
  - 5x 0.1 uF capacitors
  - 10x 3.3V TVS diode: PUSB3AB2DF [DigiKey Listed OK]

 - 1x 3x5-pin connector for I2C EEPROM programming: TSW-105-07-F-T [DigiKey Listed OK]
 - 2x 2x5 2.54mm male pin header: 3020-10-0300-00 [DigiKey Listed OK]
 - 2x 2x5 2.54mm female jumper shunt: 69145-210LF [DigiKey Listed OK]
 - 25x (in total) 2-pin female jumper 2.54mm: QPC02SXGN-RC [DigiKey Listed OK]

Development purchases:
 - SRAM breakout board [DigiKey Listed OK]
   The same breakout board can be used for the ADC and DAC, so we buy a few
 - VGA breakout board [Mouser Listed OK]

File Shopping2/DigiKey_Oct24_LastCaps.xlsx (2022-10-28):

Country of Origin may be different at time of shipment.
The HTSUS and ECCN information shown is for informational purposes only and is not a representation or warranty as to the accuracy or reliability of these classifications. All information is provided "as is" and is subject to change without notice. Any use made of the information provided is without recourse to Digi-Key and at the user's risk.
Index | Manufacturer Part Number | Manufacturer Name | Description | Availability | Stock Status | Attrition % | Requested Quantity 1 | Pack Quantity 1 | Pack Type 1 | Digi-Key Part Number 1 | Unit Price 1 | Extended Price 1 | Minimum Order Quantity 1 | Customer Reference | Requested Part Number | Lead Weeks | Datasheet | Reference Designator | US Import Tariff | Note | Part Status | RoHS Status | ECCN | HTSUS | Country of Origin | Environmental Information | Original Part numbers | Image
1 | CL31B226KQHNNNE | Samsung Electro-Mechanics | CAP CER 22UF 6.3V X7R 1206 | 547 574 | In Stock |  | 50 | 50 | Cut Tape (CT) | 1276-3146-1-ND | 2,44900 | kr 122,45 | 1 |  | 1276-3146-1-ND | 22 | https://www.samsungsem.com/kr/support/product-search/mlcc/CL31B226KQHNNNE.jsp |  | N/A |  | Active | ROHS3 Compliant | EAR99 | 8532.24.0020 | Philippines | https://www.samsungsem.com/global/support/certificate/product-stewardship.do|https://www.samsungsem.com/files/fileDown.do?key=ed1dfdfa-645e-4252-b707-17f9b1502dd1 | 1276-3146-1-ND | https://media.digikey.com/Renders/Samsung%20Electro-Mechanics%20America/Ceramic-Capacitor-CL-Series.jpg
2 | GRT31CC81E106KE01L | Murata Electronics | CAP CER 10UF 25V X6S 1206 | 8 558 | In Stock |  | 18 | 18 | Cut Tape (CT) | 490-12415-1-ND | 3,41100 | kr 61,40 | 1 |  | 490-12415-1-ND | 27 | https://search.murata.co.jp/Ceramy/image/img/A01X/G101/ENG/GRT31CC81E106KE01-01.pdf |  | N/A |  | Active | ROHS3 Compliant | EAR99 | 8532.24.0020 | Japan |  | 490-12415-1-ND | https://media.digikey.com/Renders/Murata%20Renders/1206-(3216-Metric)-1,80mm.jpg
3 | CL21A106KAYNNNG | Samsung Electro-Mechanics | CAP CER 10UF 25V X5R 0805 | 643 000 | In Stock |  | 10 | 10 | Cut Tape (CT) | 1276-6454-1-ND | 1,37700 | kr 13,77 | 1 |  | 1276-6454-1-ND | 22 | https://www.samsungsem.com/kr/support/product-search/mlcc/CL21A106KAYNNNG.jsp |  | N/A |  | Active | ROHS3 Compliant | EAR99 | 8532.24.0020 | Philippines | https://www.samsungsem.com/global/support/certificate/product-stewardship.do|https://www.samsungsem.com/files/fileDown.do?key=ed1dfdfa-645e-4252-b707-17f9b1502dd1 | 1276-6454-1-ND | https://media.digikey.com/Renders/Samsung%20Electro-Mechanics%20America/Ceramic-Capacitor-CL-Series.jpg
4 | CL21A226MQQNNNG | Samsung Electro-Mechanics | CAP CER 22UF 6.3V X5R 0805 | 1 067 221 | In Stock |  | 10 | 10 | Cut Tape (CT) | 1276-6460-1-ND | 1,00100 | kr 10,01 | 1 |  | 1276-6460-1-ND | 22 | https://media.digikey.com/pdf/Data%20Sheets/Samsung%20PDFs/CL21A226MQQNNNG_Spec.pdf |  | N/A |  | Active | ROHS3 Compliant | EAR99 | 8532.24.0020 | China | https://www.samsungsem.com/global/support/certificate/product-stewardship.do|https://www.samsungsem.com/files/fileDown.do?key=ed1dfdfa-645e-4252-b707-17f9b1502dd1 | 1276-6460-1-ND | https://media.digikey.com/Renders/Samsung%20Electro-Mechanics%20America/Ceramic-Capacitor-CL-Series.jpg

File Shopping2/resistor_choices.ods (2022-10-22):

Component | Footprint | Was | New | BUS | Comment | Changes | 2.2k | 4.7k | 10k | 1k | (All 0805)
R55 | 0805 | 2.2k | 4.7k |  | FPGA Flash ~CS pullup | Compared to schem. | -1 | 1
 |  |  |  |  |  | Negative means freed up
R7 | 0805 | 2.2k | 4.7k |  | Common pullup for DAC SYNC_T, SYNC and BLANK (2.2k used in datasheet) | Positive means used | -1 | 1
R501, R502 | 0805 | 2.2k | 10k | DDC1 | ADC1’s DDC slave MCU end pullups |  | -2 |  | 2
R503, R504 | 0805 | 2.2k | 10k | DDC2 | ADC2’s DDC slave MCU end pullups |  | -2 |  | 2
R38, R39 | 0805 | ~ | NONE | DDC2 | ADC2’s DDC level shifter low side
R32, R33 | 0805 | ~ | NONE | DDC1 | ADC1’s DDC level shifter low side
R40, R41 | 0805 | ~ | 10k | DDC2 | ADC2’s DDC level shifter high side |  |  |  | 2
R34, R35 | 0805 | ~ | 10k | DDC1 | ADC1’s DDC level shifter high side |  |  |  | 2
R12, R13 | 0805 | ~ | NONE | I2C1 | VGA out DDC level switcher low side
R14, R15 | 0805 | ~ | 10k | I2C1 | VGA out DDC level switcher high side |  |  |  | 2
R505, R506 | 0805 | 2.2k | 4.7k | I2C1 | I2C1 MCU end |  | -2 | 2
R23, R24 | 0805 | 2.2k | NONE | I2C1 | ADC2 I2C pullups |  | -2
R25, R26 | 0805 | 2.2k | 4.7k |  | ADC2 address choice pull up/down (2.2k recommended), We only need one of them |  | -2 | 1
R28, R29 | 0805 | 2.2k | NONE | I2C1 | ADC1 I2C pulluips |  | -2
R30, R31 | 0805 | 2.2k | 4.7k |  | ADC1 address choice pull up/down (2.2k recommended), We only need one of them |  | -2 | 1
R16, R17 | 0805 | 1k | 1k |  | VGA out 1.8V → 5V H/VSYNC high side
R36, R37 | 0805 | 1k | NONE |  | ADC1 5V → 3.3V H/VSYNC high side |  |  |  |  | -2
R42, R43 | 0805 | 1k | NONE |  | ADC2 5V → 3.3V H/VSYNC high side |  |  |  |  | -2
R18, R20 | 0805 | 1k | 1k |  | ADC1 5V → 3.3V H/VSYNC low side
R19, R21 | 0805 | 1k | 1k |  | ADC2 5V → 3.3V H/VSYNC low side
R529, R530, R531, R532 | 0805 | 10k | 1k |  | Keypad row shorting protection |  |  |  | -4 | 4
 |  |  |  |  |  | Extras bought per PCB | 0 | 6 | 6 | 0
 |  |  |  |  |  | Left over |  | 0 | 0 | 0

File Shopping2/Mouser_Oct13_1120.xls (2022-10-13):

VGA CENTRIFUGE 2
Mouser No | Mfr. No | Manufacturer | Customer No | Description | RoHS | Lifecycle | Order Qty. | Price (NOK) | Ext.: (NOK)
187-CL21A106KOQNNNE | CL21A106KOQNNNE | Samsung Electro-Mechanics |  | Multilayer Ceramic Capacitors MLCC - SMD/SMT 10uF+/-10% 16V X5R 2 0805 | RoHS Compliant |  | 18 | kr 0,437 | kr 7,87
187-CL21F104ZBANNNC | CL21F104ZBANNNC | Samsung Electro-Mechanics |  | Multilayer Ceramic Capacitors MLCC - SMD/SMT 100nF-20,+80% 50V Y5 0805 | RoHS Compliant |  | 111 | kr 0,245 | kr 27,20
791-0805X105K100CT | 0805X105K100CT | Walsin |  | Multilayer Ceramic Capacitors MLCC - SMD/SMT 1.0uF +-10% 10V | RoHS Compliant |  | 78 | kr 0,821 | kr 64,04
603-CC805MRX7R9BB103 | CC0805MRX7R9BB103 | YAGEO |  | Multilayer Ceramic Capacitors MLCC - SMD/SMT 50V 0.01uF X7R 0805 20% | RoHS Compliant |  | 45 | kr 0,362 | kr 16,29
791-0805B102K250CT | 0805B102K250CT | Walsin |  | Multilayer Ceramic Capacitors MLCC - SMD/SMT 1000pF +-10% 25V | RoHS Compliant |  | 18 | kr 0,821 | kr 14,78
187-CL21B472KBANNND | CL21B472KBANNND | Samsung Electro-Mechanics |  | Multilayer Ceramic Capacitors MLCC - SMD/SMT SAMSUNG | RoHS Compliant |  | 6 | kr 1,07 | kr 6,42
74-TMCP1D104MTRF | TMCP1D104MTRF | Vishay |  | Tantalum Capacitors - Solid SMD 20volts 0.10uF 20% Molded Case, 0805 | RoHS Compliant |  | 3 | kr 3,73 | kr 11,19
81-GRM32ER70J476ME0L | GRM32ER70J476ME20L | Murata |  | Multilayer Ceramic Capacitors MLCC - SMD/SMT 47UF 6.3V 20% 1210 | RoHS Compliant |  | 12 | kr 6,11 | kr 73,32
187-CL21A475KPFNNNE | CL21A475KPFNNNE | Samsung Electro-Mechanics |  | Multilayer Ceramic Capacitors MLCC - SMD/SMT 4.7uF+/-10% 10V X5R 0805 | RoHS Compliant |  | 48 | kr 0,405 | kr 19,44
187-CL32A107MPVNNNE | CL32A107MPVNNNE | Samsung Electro-Mechanics |  | Multilayer Ceramic Capacitors MLCC - SMD/SMT 100uF+/-20% 10V X5R 1210 | RoHS Compliant |  | 3 | kr 11,19 | kr 33,57
81-GRM188R70J474KA1D | GRM188R70J474KA01D | Murata |  | Multilayer Ceramic Capacitors MLCC - SMD/SMT PLEASE SEE MURATA'S SUGGESTED ALTERNATE GRM155R71A474KE01D | RoHS Compliant |  | 87 | kr 0,842 | kr 73,25
74-T55D337M010C0018 | T55D337M010C0018 | Vishay |  | Tantalum Capacitors - Polymer 330uF 10volts 20% D Case 18 Max. ESR | RoHS Compliant |  | 3 | kr 21,11 | kr 63,33
603-RC0805FR-074K7L | RC0805FR-074K7L | YAGEO |  | Thick Film Resistors - SMD 4.7 kOhms 125 mW 0805 1% | RoHS Compliant By Exemption |  | 30 | kr 0,597 | kr 17,91
603-RC0805FR-0775RL | RC0805FR-0775RL | YAGEO |  | Thick Film Resistors - SMD 75 Ohms 125 mW 0805 1% | RoHS Compliant By Exemption |  | 27 | kr 0,309 | kr 8,34
603-RC0805FR-073K83L | RC0805FR-073K83L | YAGEO |  | Thick Film Resistors - SMD 3.83 kOhms 125 mW 0805 1% | RoHS Compliant By Exemption |  | 3 | kr 1,07 | kr 3,21
71-CRCW08052K20FKEB | CRCW08052K20FKEB | Vishay |  | Thick Film Resistors - SMD 1/8watt 2.2Kohms 1% | RoHS Compliant By Exemption |  | 48 | kr 0,661 | kr 31,73
603-RC0805FR-1310KL | RC0805FR-1310KL | YAGEO |  | Thick Film Resistors - SMD 10 kOhms 250 mW 0805 1% | RoHS Compliant By Exemption |  | 69 | kr 0,309 | kr 21,32
756-WCR0805-330RFI | WCR0805-330RFI | TT Electronics |  | Thick Film Resistors - SMD 330 ohm 1% 150V General Purpose SMT | RoHS Compliant By Exemption |  | 6 | kr 1,07 | kr 6,42
652-CRT0805FZ1001ELF | CRT0805-FZ-1001ELF | Bourns |  | Thin Film Resistors - SMD 1K OHM 1% 75PPM | RoHS Compliant |  | 30 | kr 0,97 | kr 29,10
603-RE0805FRE071K5L | RE0805FRE071K5L | YAGEO |  | Thick Film Resistors - SMD 1.5 kOhms 125 mW 0805 1% | RoHS Compliant By Exemption |  | 6 | kr 1,07 | kr 6,42
534-5015 | 5015 | Keystone Electronics |  | Circuit Board Hardware - PCB MINI SMT TEST POINT | RoHS Compliant |  | 126 | kr 1,98 | kr 249,48
947-RCLAMP0524PATCT | RCLAMP0524PATCT | Semtech |  | ESD Suppressors / TVS Diodes RailClamp 4-Lines 5V 0.3pF ESD SLP2510P8 | RoHS Compliant |  | 9 | kr 12,69 | kr 114,21
947-RCLAMP3324P.TNT | RCLAMP3324P.TNT | Semtech |  | ESD Suppressors / TVS Diodes Low Capacitance 4- Line ESD Protection | RoHS Compliant |  | 3 | kr 10,55 | kr 31,65
520-ECS-2333-270-BNT | ECS-2333-270-BN-TR | ECS |  | Standard Clock Oscillators 27MHz 3.3Volt 50ppm -40 to 85C | RoHS Compliant |  | 6 | kr 11,30 | kr 67,80
595-TVP7002PZPR | TVP7002PZPR | Texas Instruments |  | Video ICs Tr 8/10B 165/110MSPS Video ADC | RoHS Compliant |  | 1 | kr 92,85 | kr 92,85
595-THS8136IPHP | THS8136IPHP | Texas Instruments |  | Digital to Analog Converters - DAC Triple 10B 180MSPS Graphics & Video DAC | RoHS Compliant |  | 1 | kr 108,63 | kr 108,63

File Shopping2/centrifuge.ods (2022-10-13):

Source: | /home/havard/Development/tdt4295/pcb/centrifuge_combined/centrifuge.kicad_sch
Date: | Wed 12 Oct 2022 10:53:36 AM CEST
Tool: | Eeschema (6.0.8)
Generator: | /usr/share/kicad/plugins/bom_csv_grouped_by_value.py
Component Count: 398
Collated Components:
 |  |  |  |  |  |  |  |  |  |  |  |  | Listed
Item | Qty | Reference(s) | Value | LibPart | Footprint | Datasheet | Order Page | Comments | Per board | Total need | Bought | To buy | Mouser | DigiKey | Already have check
1 | 4 | C1, C2, C7, C8 | 10u | Device:C_Small | Capacitor_SMD:C_0805_2012Metric_Pad1.18x1.45mm_HandSolder | ~ | https://no.mouser.com/ProductDetail/Samsung-Electro-Mechanics/CL21A106KOQNNNE | Added below | 4 | 12 | XXX | #VALUE!
2 | 37 | C3, C4, C5, C6, C9, C13, C14, C15, C20, C31, C36, C38, C42, C43, C44, C49, C60, C65, C67, C70, C71, C123, C124, C125, C126, C127, C128, C129, C130, C131, C132, C133, C134, C135, C136, C137, C138 | 0.1u | Device:C_Small | Capacitor_SMD:C_0805_2012Metric_Pad1.18x1.45mm_HandSolder | ~ | https://no.mouser.com/ProductDetail/Samsung-Electro-Mechanics/CL21F104ZBANNNC | ~ | 37 | 111 |  | 111 | X
3 | 22 | C10, C11, C12, C16, C18, C23, C26, C29, C33, C34, C35, C39, C40, C41, C45, C47, C52, C55, C58, C62, C63, C64 | 1u | Device:C_Small | Capacitor_SMD:C_0805_2012Metric_Pad1.18x1.45mm_HandSolder | ~ | https://no.mouser.com/ProductDetail/Walsin/0805X105K100CT | Added below | 22 | 66 | XXX | #VALUE!
4 | 15 | C17, C19, C21, C22, C25, C28, C32, C46, C48, C50, C51, C54, C57, C61, C68 | 10n | Device:C_Small | Capacitor_SMD:C_0805_2012Metric_Pad1.18x1.45mm_HandSolder | ~ | https://no.mouser.com/ProductDetail/YAGEO/CC0805MRX7R9BB103?qs=57cj7OiSijmskACsiRh84g%3D%3D | ~ | 15 | 45 |  | 45 | X
5 | 6 | C24, C27, C30, C53, C56, C59 | 1n | Device:C_Small | Capacitor_SMD:C_0805_2012Metric_Pad1.18x1.45mm_HandSolder | ~ | https://no.mouser.com/ProductDetail/Walsin/0805B102K250CT | ~ | 6 | 18 |  | 18 | X
6 | 2 | C37, C66 | 4.7n | Device:C_Small | Capacitor_SMD:C_0805_2012Metric_Pad1.18x1.45mm_HandSolder | ~ | https://no.mouser.com/ProductDetail/Samsung-Electro-Mechanics/CL21B472KBANNND | ~ | 2 | 6 |  | 6 | X
7 | 1 | C69 | 0.1u tantalum | Device:C_Small | Capacitor_SMD:C_0805_2012Metric_Pad1.18x1.45mm_HandSolder | ~ | https://no.mouser.com/ProductDetail/Vishay-Sprague/TMCP1D104MTRF?qs=WatphXlIDnw%2FoZNcCIT6eQ%3D%3D | ~ | 1 | 3 |  | 3 | X
8 | 4 | C72, C108, C121, C122 | 47u X5R/X7R | Device:C_Small | Capacitor_SMD:C_1210_3225Metric_Pad1.33x2.70mm_HandSolder | ~ | https://no.mouser.com/ProductDetail/Murata-Electronics/GRM32ER70J476ME20L?qs=dvNkCgDRzLg73cA9qAvMhQ%3D%3D | ~ | 4 | 12 |  | 12 | X
9 | 16 | C73, C75, C84, C86, C88, C90, C92, C94, C104, C105, C106, C107, C117, C118, C119, C120 | 4.7u | Device:C_Small | Capacitor_SMD:C_0805_2012Metric_Pad1.18x1.45mm_HandSolder | ~ | https://no.mouser.com/ProductDetail/Samsung-Electro-Mechanics/CL21A475KPFNNNE?qs=yOVawPpwOwmSlN4VFiPp3g%3D%3D | ~ | 16 | 48 |  | 48 | X
10 | 1 | C74 | 100u tantalum 1-40 mOhm or X5R/X7R | Device:C_Small | Capacitor_SMD:C_1210_3225Metric_Pad1.33x2.70mm_HandSolder | ~ | https://no.mouser.com/ProductDetail/Samsung-Electro-Mechanics/CL32A107MPVNNNE | X5R | 1 | 3 |  | 3 | X
11 | 29 | C76, C77, C78, C79, C80, C81, C83, C85, C87, C89, C91, C93, C95, C96, C97, C98, C99, C100, C101, C102, C103, C109, C110, C111, C112, C113, C114, C115, C116 | 470n | Device:C_Small | Capacitor_SMD:C_0603_1608Metric_Pad1.08x0.95mm_HandSolder | ~ | https://no.mouser.com/ProductDetail/Murata-Electronics/GRM188R70J474KA01D?qs=UOvNgVTuGCosasgf37QP%2FA%3D%3D | ~ | 29 | 87 |  | 87 | X
12 | 1 | C82 | 330u tantalum 5-40 mOhm | Device:C_Polarized_Small | Capacitor_Tantalum_SMD:CP_EIA-7343-31_Kemet-D_Pad2.25x2.55mm_HandSolder | ~ | https://no.mouser.com/ProductDetail/Vishay-Polytech/T55D337M010C0018 | ~ | 1 | 3 |  | 3 | X
13 | 12 | C501, C502, C503, C504, C505, C506, C529, C530, C531, C532, C533, C534 | 22u | Device:C | Capacitor_SMD:C_1206_3216Metric_Pad1.33x1.80mm_HandSolder | ~ | https://www.digikey.no/no/products/detail/samsung-electro-mechanics/CL31B226KQHNNNE/3888804 | ~ | 12 | 36 |  | 36 |  | X
14 | 1 | C507 | 100u | Device:C_Polarized_US | Capacitor_THT:CP_Radial_D10.0mm_P5.00mm | ~ | https://www.digikey.no/no/products/detail/panasonic-electronic-components/EEU-FC1H101/266332 | Up to 18V | 1 | 3 |  | 3 |  | X
15 | 6 | C508, C509, C510, C523, C524, C525 | 10u | Device:C | Capacitor_SMD:C_1206_3216Metric_Pad1.33x1.80mm_HandSolder | ~ | https://www.digikey.no/no/products/detail/murata-electronics/GRT31CC81E106KE01L/5416837 | Up to 18V | 6 | 18 |  | 18 |  | X
16 | 12 | C511, C512, C513, C514, C515, C516, C520, C521, C522, C526, C527, C528 | 100n | Device:C | Capacitor_SMD:C_1206_3216Metric_Pad1.33x1.80mm_HandSolder | ~ | https://www.digikey.no/no/products/detail/walsin-technology-corporation/1206B104K250CT/9355100 | Some up to 18V | 12 | 36 |  | 36 |  | X
17 | 4 | C517, C518, C519, C540 | 1u | Device:C | Capacitor_SMD:C_0805_2012Metric_Pad1.18x1.45mm_HandSolder | ~ | https://no.mouser.com/ProductDetail/Walsin/0805X105K100CT | Get extra from above | 4 | 78 |  | 78 | X
18 | 11 | C535, C536, C537, C538, C541, C542, C544, C546, C547, C548, C549 | 100n | Device:C | Capacitor_SMD:C_0805_2012Metric_Pad1.18x1.45mm_HandSolder | ~ | https://www.digikey.no/no/products/detail/taiyo-yuden/LMF212B7104KGHT/10379109 | ~ | 11 | 33 |  | 33 |  | X
19 | 2 | C539, C550 | 10u | Device:C | Capacitor_SMD:C_0805_2012Metric_Pad1.18x1.45mm_HandSolder | ~ | https://no.mouser.com/ProductDetail/Samsung-Electro-Mechanics/CL21A106KOQNNNE | Get extra from above | 2 | 18 |  | 18 | X
20 | 2 | C543, C545 | 12p | Device:C | Capacitor_SMD:C_0805_2012Metric_Pad1.18x1.45mm_HandSolder | ~ | https://www.digikey.no/no/products/detail/vishay-vitramon/VJ0805A120FXJCW1BC/8307136 | ~ | 2 | 6 |  | 6 |  | X
21 | 1 | D501 | LED_YELLOW_2V_20mA | Device:LED | Diode_SMD:D_0805_2012Metric_Pad1.15x1.40mm_HandSolder | ~ | https://www.digikey.no/no/products/detail/sunled/XZMYK54W-8/8259039 | Blinker LED (2V) | 1 | 3 |  | 3 |  | X
22 | 1 | J1 | FPGA JTAG | Connector_Generic:Conn_02x07_Odd_Even | centrifuge footprints:878311411 | ~ | https://www.digikey.no/en/products/detail/molex/0878311411/3313107 | JTAG 2x7pin 2mm | 1 | 3 | 3 | 0 |  |  | X
23 | 3 | J2, J3, J4 | Conn_01x15 | Connector_Generic:Conn_01x15 | centrifuge footprints:L77HDE15SD1CH4FVGA | ~ | https://www.digikey.no/en/products/detail/amphenol-cs-commercial-products/L77HDE15SD1CH4FVGA/4888525 | VGA ports | 3 | 9 | 9 | 0 |  |  | X
24 | 2 | J501, J516 | Conn_02x06_Odd_Even | Connector_Generic:Conn_02x06_Odd_Even | Connector_PinHeader_2.54mm:PinHeader_2x06_P2.54mm_Vertical | ~ | CUSTOM | 2x 2x6pin 2.54mm | 0 | 0 |  | 0
25 | 1 | J503 | MCU_extra | Connector:Conn_01x04_Male | Connector_PinHeader_2.54mm:PinHeader_1x04_P2.54mm_Vertical | ~ | CUSTOM | 1x4pin 2.54mm | 0 | 0 |  | 0
26 | 1 | J504 | FPGA eXtra | Connector_Generic:Conn_02x05_Odd_Even | Connector_PinHeader_2.54mm:PinHeader_2x05_P2.54mm_Vertical | ~ | CUSTOM | 2x5pin 2.54mm | 0 | 0 |  | 0
27 | 1 | J505 | FPGA_SPI | Connector:Conn_01x04_Male | Connector_PinHeader_2.54mm:PinHeader_1x04_P2.54mm_Vertical | ~ | CUSTOM | 1x4pin 2.54mm | 0 | 0 |  | 0
28 | 1 | J506 | DDCI2C2 | Connector:Conn_01x02_Male | Connector_PinHeader_2.54mm:PinHeader_1x02_P2.54mm_Vertical | ~ | CUSTOM | 1x2pin 2.54mm | 0 | 0 |  | 0
29 | 1 | J507 | ADC_I2C | Connector:Conn_01x02_Male | Connector_PinHeader_2.54mm:PinHeader_1x02_P2.54mm_Vertical | ~ | CUSTOM | 1x2pin 2.54mm | 0 | 0 |  | 0
30 | 1 | J508 | ADC_RST | Connector:Conn_01x02_Male | Connector_PinHeader_2.54mm:PinHeader_1x02_P2.54mm_Vertical | ~ | CUSTOM | 1x2pin 2.54mm | 0 | 0 |  | 0
31 | 1 | J509 | USB_B_Micro | Connector:USB_B_Micro | Connector_USB:USB_Micro-B_Molex-105017-0001 | ~ | https://www.digikey.no/no/products/detail/molex/1050171001/5293188 | Usb micro | 1 | 3 |  | 3 |  | X
32 | 1 | J510 | Barrel_Jack | Connector:Barrel_Jack_Switch | Connector_BarrelJack:BarrelJack_CUI_PJ-102AH_Horizontal | ~ | https://www.digikey.no/no/products/detail/tensility-international-corp/54-00133/9685442 | Power barrel jack | 1 | 3 |  | 3 |  | X
33 | 1 | J511 | PowerIn | Connector:Conn_01x02_Male | Connector_PinHeader_2.54mm:PinHeader_1x02_P2.54mm_Vertical | ~ | CUSTOM | 1x2pin 2.54mm | 0 | 0 |  | 0
34 | 1 | J512 | PowerPads | Connector:Conn_01x02_Male | centrifuge_mcu:PowerPads | ~ | BUILTIN | ~ | 0 | 0 |  | 0
35 | 1 | J513 | SD_Card | Connector:SD_Card | Connector_Card:SD_Kyocera_145638009511859+ | http://portal.fciconnect.com/Comergent//fci/drawing/10067847.pdf | https://www.digikey.no/en/products/detail/amphenol-cs-fci/10067847-001RLF/2283478 | SD card holder | 1 | 3 | 3 | 0 |  |  | X
36 | 1 | J514 | DEBUG | Connector_Generic:Conn_02x10_Odd_Even | Connector_PinHeader_1.27mm:PinHeader_2x10_P1.27mm_Vertical | ~ | https://www.digikey.no/en/products/detail/cnc-tech/3220-20-0100-00/3883663 | Cortex Debug+ETM Connector (1.27mm) | 1 | 3 | 3 | 0 |  |  | X
37 | 1 | J515 | Extra MCU GPIO | Connector_Generic:Conn_02x04_Odd_Even | Connector_PinHeader_2.54mm:PinHeader_2x04_P2.54mm_Vertical | ~ | CUSTOM | 2x4pin 2.54mm | 0 | 0 |  | 0
38 | 1 | J517 | DDCI2C1 | Connector:Conn_01x02_Male | Connector_PinHeader_2.54mm:PinHeader_1x02_P2.54mm_Vertical | ~ | CUSTOM | 1x2pin 2.54mm | 0 | 0 |  | 0
39 | 1 | J518 | FPGA 6XTRA | Connector_Generic:Conn_02x03_Odd_Even | Connector_PinHeader_2.54mm:PinHeader_2x03_P2.54mm_Vertical | ~ | CUSTOM | 2x3pin 2.54mm | 0 | 0 |  | 0
40 | 1 | J519 | FPGA EXTR4 | Connector_Generic:Conn_02x02_Odd_Even | Connector_PinHeader_2.54mm:PinHeader_2x02_P2.54mm_Vertical | ~ | CUSTOM | 2x2pin 2.54mm | 0 | 0 |  | 0
41 | 7 | JP1, JP10, JP15, JP16, JP17, JP22, JP23 | Jumper_2_Bridged | Jumper:Jumper_2_Bridged | Jumper:SolderJumper-2_P1.3mm_Bridged_Pad1.0x1.5mm | ~ | BUILTIN | ~ | 0 | 0 |  | 0
42 | 2 | JP8, JP9 | Jumper_3_Open | Jumper:Jumper_3_Open | Jumper:SolderJumper-3_P1.3mm_Open_Pad1.0x1.5mm_NumberLabels | ~ | BUILTIN | ~ | 0 | 0 |  | 0
43 | 8 | JP11, JP12, JP13, JP14, JP18, JP19, JP20, JP21 | SolderJumper_3_Bridged12 | Jumper:SolderJumper_3_Bridged12 | Jumper:SolderJumper-3_P1.3mm_Open_Pad1.0x1.5mm_NumberLabels | ~ | BUILTIN | ~ | 0 | 0 |  | 0
44 | 3 | L501, L502, L504 | 1.5u | Device:L | centrifuge_mcu:L_Sumida_CR75 | ~ | https://www.digikey.no/no/products/detail/sumida-america-inc/0415CDMCCDS-1R5MC/9490383 | Ip>2.5A, Irms>2.1A | 3 | 9 |  | 9 |  | X
45 | 2 | L503, L505 | 2.2u | Device:L | Inductor_SMD:L_Vishay_IHLP-2020 | ~ | https://www.digikey.no/no/products/detail/vishay-dale/IHLP2020CZER2R2M5A/13985228 | Ip>2.9A, Irms>2.1A | 2 | 6 |  | 6 |  | X
46 | 1 | L506 | 3.3u | Device:L | centrifuge_mcu:L_TDK_7065 | ~ | https://www.digikey.no/no/products/detail/tdk-corporation/SPM6545VT-3R3M-D/14638088 | Ipeek>3.7A, Irms>2.3A | 1 | 3 |  | 3 |  | X
47 | 6 | Q1, Q2, Q3, Q4, Q5, Q6 | BSN20 | Device:Q_NMOS_GSD | Package_TO_SOT_SMD:SOT-23 | https://www.diodes.com/assets/Datasheets/ds31898.pdf | https://www.digikey.no/en/products/detail/diodes-incorporated/BSN20-7/2756034 | I2C level shifter | 6 | 18 | 18 | 0 |  |  | X
48 | 1 | Q501 | Q_PMOS_DGS | Device:Q_PMOS_GDS | Package_TO_SOT_THT:TO-220-3_Vertical | ~ | https://www.digikey.no/no/products/detail/infineon-technologies/SPP80P06PHXKSA1/2081673 | Polarity pmos | 1 | 3 |  | 3 |  | X
49 | 1 | Q502 | Q_NMOS_GSD | Device:Q_NMOS_GSD | Package_TO_SOT_SMD:SOT-323_SC-70_Handsoldering | ~ | https://www.digikey.no/no/products/detail/panjit-international-inc/PJC138K-AU-R1-000A1/14661065 | Blinker LED nmos driver | 1 | 3 |  | 3 |  | X
50 | 4 | R1, R2, R11, R47 | 4.7k | Device:R_Small | Resistor_SMD:R_0805_2012Metric_Pad1.20x1.40mm_HandSolder | ~ | https://no.mouser.com/ProductDetail/YAGEO/RC0805FR-074K7L | Added 18 extra | 4 | 30 |  | 30 | X
51 | 9 | R3, R4, R5, R48, R49, R50, R51, R52, R53 | 75 | Device:R_Small | Resistor_SMD:R_0805_2012Metric_Pad1.20x1.40mm_HandSolder | ~ | https://no.mouser.com/ProductDetail/YAGEO/RC0805FR-0775RL | ~ | 9 | 27 |  | 27 | X
52 | 1 | R6 | 3.8k | Device:R_Small | Resistor_SMD:R_0805_2012Metric_Pad1.20x1.40mm_HandSolder | ~ | https://no.mouser.com/ProductDetail/YAGEO/RC0805FR-073K83L?qs=sGAEpiMZZMtlubZbdhIBIJv49G1poxg9o6TOu1v2tWs%3D | ~ | 1 | 3 |  | 3 | X
53 | 10 | R7, R23, R24, R25, R26, R28, R29, R30, R31, R55 | 2.2k | Device:R_Small | Resistor_SMD:R_0805_2012Metric_Pad1.20x1.40mm_HandSolder | ~ | https://no.mouser.com/ProductDetail/Vishay-Dale/CRCW08052K20FKEB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 | ~ | 10 | 30 | XXX | #VALUE!
54 | 5 | R8, R9, R44, R45, R46 | 10k | Device:R_Small | Resistor_SMD:R_0805_2012Metric_Pad1.20x1.40mm_HandSolder | ~ | https://no.mouser.com/ProductDetail/YAGEO/RC0805FR-1310KL?qs=sGAEpiMZZMtlubZbdhIBIHucEnbnlIRRGobQQ23C9vc%3D | Added 18 extra | 5 | 33 | XXX | #VALUE!
55 | 2 | R10, R54 | 330 | Device:R_Small | Resistor_SMD:R_0805_2012Metric_Pad1.20x1.40mm_HandSolder | ~ | https://no.mouser.com/ProductDetail/Welwyn-Components-TT-Electronics/WCR0805-330RFI | ~ | 2 | 6 |  | 6 | X
56 | 3 | R12, R32, R38 | vga_ddc_sda_pullup_l | Device:R_Small | Resistor_SMD:R_0805_2012Metric_Pad1.20x1.40mm_HandSolder | ~ | CUSTOM | Added 18x to 10k | 3 | 9 | 9 | 0
57 | 3 | R13, R33, R39 | vga_ddc_scl_pullup_l | Device:R_Small | Resistor_SMD:R_0805_2012Metric_Pad1.20x1.40mm_HandSolder | ~ | CUSTOM | And 18x to 4k7 | 3 | 9 | 9 | 0
58 | 3 | R14, R34, R40 | vga_ddc_sda_pullup_h | Device:R_Small | Resistor_SMD:R_0805_2012Metric_Pad1.20x1.40mm_HandSolder | ~ | CUSTOM | And then we can | 3 | 9 | 9 | 0
59 | 3 | R15, R35, R41 | vga_ddc_scl_pullup_h | Device:R_Small | Resistor_SMD:R_0805_2012Metric_Pad1.20x1.40mm_HandSolder | ~ | CUSTOM | test whats needed | 3 | 9 | 9 | 0
60 | 10 | R16, R17, R18, R19, R20, R21, R36, R37, R42, R43 | 1k | Device:R_Small | Resistor_SMD:R_0805_2012Metric_Pad1.20x1.40mm_HandSolder | ~ | https://no.mouser.com/ProductDetail/Bourns/CRT0805-FZ-1001ELF | ~ | 10 | 30 |  | 30 | X
61 | 2 | R22, R27 | 1.5k | Device:R_Small | Resistor_SMD:R_0805_2012Metric_Pad1.20x1.40mm_HandSolder | ~ | https://no.mouser.com/ProductDetail/YAGEO/RE0805FRE071K5L | ~ | 2 | 6 |  | 6 | X
62 | 6 | R501, R502, R503, R504, R505, R506 | 2.2k | Device:R | Resistor_SMD:R_0805_2012Metric_Pad1.20x1.40mm_HandSolder | ~ | https://no.mouser.com/ProductDetail/Vishay-Dale/CRCW08052K20FKEB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 | Includes above XXX | 6 | 48 |  | 48 | X
63 | 1 | R507 | 5.6M | Device:R | Resistor_SMD:R_0805_2012Metric_Pad1.20x1.40mm_HandSolder | ~ | https://www.digikey.no/no/products/detail/stackpole-electronics-inc/RMCF0805FT5M60/1713201 | 1% | 1 | 3 |  | 3 |  | X
64 | 1 | R508 | 6.81k | Device:R | Resistor_SMD:R_0805_2012Metric_Pad1.20x1.40mm_HandSolder | ~ | https://www.digikey.no/no/products/detail/stackpole-electronics-inc/RNCP0805FTD6K81/2240257 | 1% | 1 | 3 |  | 3 |  | X
65 | 6 | R509, R511, R513, R518, R520, R522 | 22.1k | Device:R | Resistor_SMD:R_0805_2012Metric_Pad1.20x1.40mm_HandSolder | ~ | https://www.digikey.no/no/products/detail/stackpole-electronics-inc/RNCP0805FTD22K1/2240273 | 1% | 6 | 18 |  | 18 |  | X
66 | 1 | R510 | 33k | Device:R | Resistor_SMD:R_0805_2012Metric_Pad1.20x1.40mm_HandSolder | ~ | https://www.digikey.no/no/products/detail/yageo/AC0805FR-0733KL/5896774 | 1% | 1 | 3 |  | 3 |  | X
67 | 2 | R512, R519 | 73.2k | Device:R | Resistor_SMD:R_0805_2012Metric_Pad1.20x1.40mm_HandSolder | ~ | https://www.digikey.no/no/products/detail/yageo/RC0805FR-0773K2L/728129 | 1% | 2 | 6 |  | 6 |  | X
68 | 12 | R514, R515, R516, R523, R524, R525, R526, R527, R529, R530, R531, R532 | 10k | Device:R | Resistor_SMD:R_0805_2012Metric_Pad1.20x1.40mm_HandSolder | ~ | https://no.mouser.com/ProductDetail/YAGEO/RC0805FR-1310KL?qs=sGAEpiMZZMtlubZbdhIBIHucEnbnlIRRGobQQ23C9vc%3D | Includes above XXX | 12 | 69 |  | 69 | X
69 | 1 | R517 | 30.1k | Device:R | Resistor_SMD:R_0805_2012Metric_Pad1.20x1.40mm_HandSolder | ~ | https://www.digikey.no/no/products/detail/yageo/RC0805FR-0730K1L/727845 | 1% | 1 | 3 |  | 3 |  | X
70 | 1 | R521 | 124k | Device:R | Resistor_SMD:R_0805_2012Metric_Pad1.20x1.40mm_HandSolder | ~ | https://www.digikey.no/no/products/detail/stackpole-electronics-inc/RMCF0805FT124K/1760657 | 1% | 1 | 3 |  | 3 |  | X
71 | 1 | R528 | 62 | Device:R | Resistor_SMD:R_0805_2012Metric_Pad1.20x1.40mm_HandSolder | ~ | https://www.digikey.no/no/products/detail/yageo/AC0805FR-0762RL/5896938 | ~ | 1 | 3 |  | 3 |  | X
72 | 1 | SW1 | SW_MEC_5E | Switch:SW_MEC_5E | centrifuge footprints:SW_Push_1P1T_NO_6x6mm_H9.5mm_modified | https://www.citrelay.com/Catalog%20Pages/SwitchCatalog/CS1102.pdf | https://www.digikey.no/en/products/detail/cit-relay-and-switch/CS11025-0F100/16607790 | Push button | 1 | 3 |  | 3 |  | X
73 | 42 | TP1, TP2, TP3, TP4, TP5, TP10, TP11, TP12, TP13, TP14, TP15, TP16, TP17, TP18, TP19, TP20, TP21, TP22, TP23, TP24, TP25, TP26, TP27, TP28, TP29, TP30, TP31, TP32, TP33, TP34, TP35, TP36, TP37, TP38, TP39, TP40, TP41, TP42, TP43, TP44, TP501, TP502 | TestPoint | Connector:TestPoint | TestPoint:TestPoint_Keystone_5015_Micro-Minature | ~ | https://no.mouser.com/ProductDetail/Keystone-Electronics/5015?qs=qOqV1E1P08ShW56PtUq2FA%3D%3D | Hook test points | 42 | 126 |  | 126 | X
74 | 1 | U1 | XC7A100T-FTG256 | FPGA_Xilinx_Artix7:XC7A100T-FTG256 | Package_BGA:Xilinx_FTG256 | ~ | ~ | From Asbjørn | 1 | 3 | 3 | 0
75 | 1 | U2 | S25FL127SABMFV10 | centrifuge_symbols:S25FL127SABMFV10 | Package_SO:SOIC-8_5.23x5.23mm_P1.27mm | ~ | https://www.digikey.no/en/products/detail/cypress-semiconductor-corp/S25FL127SABMFV101/5788556 | Config Flash | 1 | 3 | 3 | 0 |  |  | X
76 | 1 | U3 | CY7C1370KV33 | centrifuge_symbols:CY7C1370KV33 | Package_QFP:PQFP-100_14x20mm_P0.65mm | https://www.infineon.com/dgdl/Infineon-CY7C1370KV33_CY7C1370KVE33_CY7C1372KV33_CY7C1372KVE33_18-Mbit_(512_K_36_1_M_18)_Pipelined_SRAM_with_NoBL_Architecture_(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 | https://www.digikey.no/en/products/detail/cypress-semiconductor-corp/CY7C1372KV33-200AXC/5982740 | SRAM | 1 | 3 | 5 | -2 |  |  | X
77 | 2 | U4, U8 | TVP7002 | centrifuge_symbols:TVP7002 | centrifuge footprints:TQFP-100-1EP_14x14mm_P0.5mm_EP5x5mm_ThermalVias_elprint | https://www.ti.com/lit/ds/symlink/tvp7002.pdf | https://no.mouser.com/ProductDetail/595-TVP7002PZPR | ADC | 2 | 7 | 6 | 1 | X |  | X
78 | 1 | U5 | THS8136 | centrifuge_symbols:THS8136 | Package_QFP:LQFP-48-1EP_7x7mm_P0.5mm_EP3.6x3.6mm | https://www.ti.com/lit/ds/symlink/ths8136.pdf | https://no.mouser.com/ProductDetail/595-THS8136IPHP | DAC | 1 | 4 | 3 | 1 | X |  | X
79 | 3 | U6, U9, U11 | LSF0102 | centrifuge_symbols:LSF0102 | Package_SO:VSSOP-8_2.3x2mm_P0.5mm | https://no.mouser.com/datasheet/2/916/LSF0102-1839907.pdf | https://www.digikey.no/no/products/detail/nexperia-usa-inc/LSF0102DCH/13574967 | Level shifter | 3 | 9 | 18 | -9 |  |  | X
80 | 3 | U7, U13, U14 | RCLAMP0524PATCT | centrifuge_symbols:RCLAMP0524PATCT | Package_DFN_QFN:Diodes_UDFN-10_1.0x2.5mm_P0.5mm | https://no.mouser.com/datasheet/2/761/SEMT_S_A0005071119_1-2575775.pdf | https://no.mouser.com/ProductDetail/Semtech/RCLAMP0524PATCT?qs=rBWM4%252BvDhIcnc1nesEh7XA%3D%3D | 5V TVS / ESP diodes | 3 | 9 |  | 9 | X
81 | 2 | U10, U12 | M24C02-WMN | Memory_EEPROM:M24C02-WMN | Package_SO:SOIC-8_3.9x4.9mm_P1.27mm | http://www.st.com/content/ccc/resource/technical/document/datasheet/b0/d8/50/40/5a/85/49/6f/DM00071904.pdf/files/DM00071904.pdf/jcr:content/translations/en.DM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 | https://www.digikey.no/en/products/detail/stmicroelectronics/M24C02-WMN6TP/1663568 | EEPROM | 2 | 6 | 6 | 0 |  |  | X
82 | 1 | U15 | RCLAMP3324P.TNT | centrifuge_symbols:RCLAMP3324P.TNT | Package_DFN_QFN:Diodes_UDFN-10_1.0x2.5mm_P0.5mm | https://no.mouser.com/datasheet/2/761/SEMT_S_A0002540573_1-2575715.pdf | https://no.mouser.com/ProductDetail/Semtech/RCLAMP3324P.TNT?qs=rBWM4%252BvDhIcjIdOyxs8eng%3D%3D | 3.3V TVS / ESP diodes | 1 | 3 |  | 3 | X
83 | 1 | U501 | DFR0555 | mcu_centrifuge_library:DFR0555 | Connector_PinHeader_2.54mm:PinHeader_1x04_P2.54mm_Vertical | ~ | CUSTOM | 1x4pin 2.54mm | 0 | 0 |  | 0
84 | 1 | U502 | LCD16x2L | mcu_centrifuge_library:LCD16x2L | centrifuge_mcu:DFR0555 | ~ | https://www.digikey.no/en/products/detail/dfrobot/DFR0555/9356340 | LCD screen | 1 | 3 | 3 | 0 |  |  | X
85 | 3 | U503, U504, U505 | TPS54294 | mcu_centrifuge_library:TPS54294 | centrifuge_mcu:TSSOP-16-1EP_4.4x5mm_P0.65mm_EP3x3mm_ThermalVias_EXTRA | ~ | ~ | From Asbjørn | 3 | 9 | 9 | 0
88 | 1 | U506 | EFM32GG990F1024 | :EFM32GG990F1024_2 | centrifuge_mcu:BGA-112_9.0x9.0mm_Layout11x11_P0.8mm_Ball0.4mm_Pad0.35mm_NSMD | ~ | ~ | From Asbjørn | 1 | 3 | 3 | 0
89 | 1 | U507 | 4x4_keyboard | mcu_centrifuge_library:4x4_keyboard | centrifuge_mcu:Adafruit 3844 | https://no.mouser.com/ProductDetail/Adafruit/3844?qs=qSfuJ%252Bfl%2Fd6WS5%252BJGim1hw%3D%3D | https://no.mouser.com/ProductDetail/485-3844 | 4x4 Keypad | 1 | 3 | 3 | 0 |  |  | X
90 | 2 | X1, X2 | ECS-2333-270-BN | centrifuge_symbols:ECS-2333-xxx-xx | Oscillator:Oscillator_SMD_EuroQuartz_XO32-4Pin_3.2x2.5mm_HandSoldering | https://no.mouser.com/datasheet/2/122/ecs-2325-2333-8384.pdf | https://no.mouser.com/ProductDetail/ECS/ECS-2333-270-BN-TR | ADC crystals | 2 | 6 |  | 6 | X
91 | 1 | X3 | EC2620TTS-100.000MTR | centrifuge_symbols:EC2620TTS-100.000MTR | Oscillator:Oscillator_SMD_EuroQuartz_XO91-4Pin_7.0x5.0mm_HandSoldering | https://no.mouser.com/datasheet/2/3/EC26-1903611.pdf | https://no.mouser.com/ProductDetail/669-EC2620TTS-100T | FPGA 100MHz crystal | 1 | 3 | 3 | 0 |  |  | X
92 | 1 | Y501 | VXM7-1366-48M0000000 | Device:Crystal_GND24 | centrifuge_mcu:Crystal_SMD_TXC_7M-4Pin_3.2x2.5mm_TIGHT | ~ | https://www.digikey.no/no/products/detail/microchip-technology/VXM7-1366-48M0000000/13175116 | MCU crystal | 1 | 3 |  | 3 |  | X
 |  |  |  |  |  |  | https://www.digikey.no/no/products/detail/trinamic-motion-control-gmbh/CABLE-PH04/9381900 | Extra LCD cable |  | 1 |  | 1 |  | X
 |  |  |  |  |  |  | https://www.digikey.no/en/products/detail/amphenol-cs-fci/69145-210LF/1528094 | 2x5pin 2.54mm shunt | 1 | 3 | 6 | -3 |  |  | X
 |  |  |  |  |  |  | https://www.digikey.no/en/products/detail/sullins-connector-solutions/QPC02SXGN-RC/2618262 | 2-pin shunt | 1 | 3 | 6 | -3 |  |  | 6, not 25
 |  |  |  |  |  |  | https://www.digikey.no/en/products/detail/sullins-connector-solutions/PRPC018DFAN-RC/2775396 | 2x18pin break 2.54mm | 2 | 6 |  | 6 |  | X
 |  |  |  |  |  |  | https://www.digikey.no/en/products/detail/sullins-connector-solutions/PRPC040SACN-RC/2776066 | 1x40pin break 2.54mm | 2 | 8 |  | 8 |  | X
 |  |  |  |  |  |  | https://www.digikey.no/en/products/detail/sullins-connector-solutions/PPTC081LFBN-RC/810147 | 1x8pin female for keypad | 1 | 3 |  | 3 |  | X
 |  |  |  |  |  |  |  |  |  | 0 |  | 0
 |  |  |  |  |  |  |  |  |  | 0 |  | 0
 |  |  |  |  |  |  |  |  |  |  |  | 0
 |  |  |  |  |  |  |  |  |  |  |  | 0
 |  |  |  |  |  |  |  |  |  |  |  | 0
 |  |  |  |  |  |  |  |  |  |  |  | 0
 |  |  |  |  |  |  |  |  |  |  |  | 0
 |  |  |  |  |  |  |  |  |  |  |  | 0
 |  |  |  |  |  |  |  |  |  |  |  | 0
 |  |  |  |  |  |  |  |  |  |  |  | 0
 |  |  |  |  |  |  |  |  |  |  |  | 0
 |  |  |  |  |  |  |  |  |  |  |  | 0
 |  |  |  |  |  |  |  |  |  |  |  | 0
 |  |  |  |  |  |  |  |  |  |  |  | 0
 |  |  |  |  |  |  |  |  |  |  |  | 0
 |  |  |  |  |  |  |  |  |  |  |  | 0
 |  |  |  |  |  |  |  |  |  |  |  | 0
 |  |  |  |  |  |  |  |  |  |  |  | 0
 |  |  |  |  |  |  |  |  |  |  |  | 0
 |  |  |  |  |  |  |  |  |  |  |  | 0
 |  |  |  |  |  |  |  |  |  |  |  | 0
 |  |  |  |  |  |  |  |  |  |  |  | 0
 |  |  |  |  |  |  | https://www.digikey.no/en/products/detail/schmartboard-inc/202-0011-01/9559300 | QFP 32-100 0.5mm breakout |  | 4 |  | 4 |  | X
 |  |  |  |  |  |  | https://www.digikey.no/en/products/detail/nexperia-usa-inc/PUSB3AB2DFZ/12325057 | TVS DIODE, wont use |  | 0 | 30 | -30 |  |  | X
 |  |  |  |  |  |  | https://www.digikey.no/en/products/detail/cnc-tech/3020-10-0300-00/3441727 | 2x5pin SMD, wont use |  | 0 | 6 | -6 |  |  | X
 |  |  |  |  |  |  | https://www.digikey.no/en/products/detail/samtec-inc/TSW-105-07-F-T/6692070 | 3x5 pin, wont use |  | 0 | 3 | -3 |  |  | X
 |  |  |  |  |  |  | https://www.digikey.no/en/products/detail/fox-electronics/FO7HSCDE48-0-T1/12160237 | Wrong 48MHz oscillator |  | 0 | 3 | -3 |  |  | X
 |  |  |  |  |  |  | https://www.digikey.no/en/products/detail/adafruit-industries-llc/5252/15841478 | microSD card 512MB |  | 1 | 1 | 0 |  |  | X
 |  |  |  |  |  |  | https://www.digikey.no/en/products/detail/schmartboard-inc/202-0010-02/9559360 | QFP breakout 0.65mm |  | 3 | 3 | 0 |  |  | X
 |  |  |  |  |  |  | https://no.mouser.com/ProductDetail/992-DB15F-VGA-TERM | VGA breakout |  | 1 | 1 | 0 |  |  | X
Replaced:
80 | 3 | U7, U13, U14 | PESD4USB5B-TTS | centrifuge_symbols:PESD4USB5B-TTS | Package_DFN_QFN:Diodes_UDFN-10_1.0x2.5mm_P0.5mm | https://no.mouser.com/datasheet/2/916/PESD4USB5B_TTS-2395695.pdf | https://no.mouser.com/ProductDetail/Nexperia/PESD4USB5B-TTSX?qs=ljCeji4nMDmS4Q%2FwzdnFVQ%3D%3D | 5V TVS diodes for VGA | 3 | 9 |  | 9
82 | 1 | U15 | D5V0FS4U10LP | centrifuge_symbols:D5V0FS4U10LP | Package_DFN_QFN:Diodes_UDFN-10_1.0x2.5mm_P0.5mm | https://www.diodes.com/assets/Datasheets/D5V0FS4U10LP.pdf | https://www.digikey.no/en/products/detail/diodes-incorporated/D5V0FS4U10LP-7/7930773 | 3.3V TVS / ESP diodes | 1 | 3 |  | 3

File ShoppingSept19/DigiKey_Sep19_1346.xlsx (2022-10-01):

Country of Origin may be different at time of shipment.
The HTSUS and ECCN information shown is for informational purposes only and is not a representation or warranty as to the accuracy or reliability of these classifications. All information is provided "as is" and is subject to change without notice. Any use made of the information provided is without recourse to Digi-Key and at the user's risk.
Index | Manufacturer Part Number | Manufacturer Name | Description | Availability | Stock Status | Attrition % | Requested Quantity 1 | Pack Quantity 1 | Pack Type 1 | Digi-Key Part Number 1 | Unit Price 1 | Extended Price 1 | Minimum Order Quantity 1 | Customer Reference | Requested Part Number | Lead Weeks | Datasheet | Reference Designator | US Import Tariff | Note | Part Status | RoHS Status | ECCN | HTSUS | Country of Origin | Environmental Information | Original Part numbers | Image
1 | S25FL127SABMFV101 | Cypress Semiconductor Corp | IC FLASH 128MBIT SPI/QUAD 8SOIC | 5 276 | In Stock |  | 3 | 3 | Tube | 428-4207-ND | 43,74000 | kr 131,22 | 1 |  | 428-4207-ND | 52 | https://www.infineon.com/dgdl/Infineon-S25FL127S_128-Mb_(16_MB)_3.0_V_SPI_Flash_Memory-DataSheet-v11_00-EN.pdf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 |  | May apply on shipments to the U.S. |  | Active | ROHS3 Compliant | 3A991B1A | 8542.32.0071 | China | https://www.cypress.com/file/199231/download | 428-4207-ND | //media.digikey.com/Renders/Cypress%20Semi%20Renders/8-SOIC_751.jpg
2 | CY7C1372KV33-200AXC | Cypress Semiconductor Corp | IC SRAM 18MBIT PARALLEL 100TQFP | 56 | In Stock |  | 5 | 5 | Tray | 2015-CY7C1372KV33-200AXC-ND | 97,10000 | kr 485,50 | 1 |  | 2015-CY7C1372KV33-200AXC-ND | 42 | https://www.infineon.com/dgdl/Infineon-CY7C1370KV33_CY7C1370KVE33_CY7C1372KV33_CY7C1372KVE33_18-Mbit_(512_K_36_1_M_18)_Pipelined_SRAM_with_NoBL_Architecture_(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 |  | N/A |  | Active | ROHS3 Compliant | 3A991B2A | 8542.32.0041 | Taiwan | https://www.cypress.com/file/199231/download | 2015-CY7C1372KV33-200AXC-ND | //media.digikey.com/Renders/Cypress%20Semi%20Renders/428;51-85050;A;100.jpg
3 | 202-0010-02 | Schmartboard, Inc. | QFP, 36-100 PINS 0.65MM PITCH, 2 | 15 | In Stock |  | 3 | 3 | Bag | 1988-1081-ND | 100,10000 | kr 300,30 | 1 |  | 1988-1081-ND | 3 | https://schmartboard.com/content/Brochures/202-0010-02.pdf |  | May apply on shipments to the U.S. |  | Active | ROHS3 Compliant | EAR99 | 8534.00.0095 | China |  | 1988-1081-ND | //media.digikey.com/photos/Schmartboard,%20Inc/MFG_202-0010-02.jpg
4 | L77HDE15SD1CH4FVGA | Amphenol ICC (Commercial Products) | CONN D-SUB HD RCPT 15P R/A SLDR | 202 | In Stock |  | 9 | 9 | Tray | L77HDE15SD1CH4FVGA-ND | 15,22000 | kr 136,98 | 1 |  | L77HDE15SD1CH4FVGA-ND | 14 | https://cdn.amphenol-cs.com/media/wysiwyg/files/drawing/l77hde15sd1ch4fvga.pdf |  | May apply on shipments to the U.S. |  | Active | RoHS Compliant | EAR99 | 8536.69.4040 | China |  | L77HDE15SD1CH4FVGA-ND | //media.digikey.com/Photos/Amphenol%20Photos/L77HDE15SD1CH4FVGA.jpg
5 | 10067847-001RLF | Amphenol ICC (FCI) | CONN SD CARD PUSH-PUSH SMD | 20 964 | In Stock |  | 3 | 3 | Cut Tape (CT) | 609-3956-1-ND | 23,22000 | kr 69,66 | 1 |  | 609-3956-1-ND | 8 | https://www.amphenol-icc.com/media/wysiwyg/files/drawing/10067847.pdf |  | May apply on shipments to the U.S. |  | Active | RoHS Compliant | EAR99 | 8536.69.4040 | China |  | 609-3956-1-ND | //media.digikey.com/photos/FCI%20Photos/10067847-001RLF.jpg
6 | 5252 | Adafruit Industries LLC | 512MB MICRO SD MEMORY CARD | 45 | In Stock |  | 1 | 1 | Bulk | 1528-5252-ND | 49,55000 | kr 49,55 | 1 |  | 1528-5252-ND | 2 |  |  | N/A |  | Active | Unknown | 3A991B1A | 8523.51.0000 | China |  | 1528-5252-ND | //media.digikey.com/Photos/Adafruit%20Industries%20LLC/MFG_5252.jpg
7 | DFR0555 | DFRobot | LCD MOD 32DIG 16X2 TRANSMISV WHT | 6 | In Stock |  | 3 | 3 | Bulk | 1738-1411-ND | 99,10000 | kr 297,30 | 1 |  | 1738-1411-ND | 4 | https://raw.githubusercontent.com/Arduinolibrary/DFRobot_Gravity_I2C_LCD1602_Display_module/master/LCD%20Datasheet.pdf |  | May apply on shipments to the U.S. |  | Active | ROHS3 Compliant | EAR99 | 8524.91.9000 | China |  | 1738-1411-ND | //media.digikey.com/Photos/DFRobot/DFR0555.jpg
8 | M24C02-WMN6TP | STMicroelectronics | IC EEPROM 2KBIT I2C 400KHZ 8SO | 126 676 | In Stock |  | 6 | 6 | Cut Tape (CT) | 497-8552-1-ND | 1,70000 | kr 10,20 | 1 |  | 497-8552-1-ND | 99 | https://www.st.com/content/ccc/resource/technical/document/datasheet/b0/d8/50/40/5a/85/49/6f/DM00071904.pdf/files/DM00071904.pdf/jcr:content/translations/en.D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 |  | May apply on shipments to the U.S. |  | Active | ROHS3 Compliant | EAR99 | 8542.32.0051 | China |  | 497-8552-1-ND | //media.digikey.com/Renders/STMicro%20Renders/497~8SOIC-3.9~~8.jpg
9 | BSN20-7 | Diodes Incorporated | MOSFET N-CH 50V 500MA SOT23 | 139 504 | In Stock |  | 18 | 18 | Cut Tape (CT) | BSN20-7DICT-ND | 2,67300 | kr 48,11 | 1 |  | BSN20-7DICT-ND | 52 | https://www.diodes.com/assets/Datasheets/ds31898.pdf |  | May apply on shipments to the U.S. |  | Active | ROHS3 Compliant | EAR99 | 8541.21.0095 | China | https://www.diodes.com/assets/Quality-Reliability-Docs/Master_CofC.pdf | BSN20-7DICT-ND | //media.digikey.com/Photos/Diodes%20Photos/SOT-23-3%20PKG.jpg
10 | FO7HSCDE48.0-T1 | Fox Electronics | OSC XO 48MHZ 3.3V HCMOS | 2 000 | In Stock |  | 3 | 3 | Cut Tape (CT) | 631-FO7HSCDE48.0-T1CT-ND | 24,62000 | kr 73,86 | 1 |  | 631-FO7HSCDE48.0-T1CT-ND | 38 | https://abracon.com/datasheets/Fox/FO7HS.pdf?utm_source=foxonline.com&utm_medium=301 |  | N/A |  | Active | ROHS3 Compliant | EAR99 | 8542.39.0001 | Taiwan |  | 631-FO7HSCDE48.0-T1CT-ND | //media.digikey.com/Photos/Fox Elect Photos/MFG_FO7HSCDM32.0-BULK.jpg
11 | LSF0102DCH | Nexperia USA Inc. | LSF0102DC/SOT765/VSSOP8 | 606 | In Stock |  | 18 | 18 | Cut Tape (CT) | 1727-LSF0102DCHCT-ND | 5,93600 | kr 106,85 | 1 |  | 1727-LSF0102DCHCT-ND | 27 | https://assets.nexperia.com/documents/data-sheet/LSF0102.pdf |  | May apply on shipments to the U.S. |  | Active | ROHS3 Compliant | EAR99 | 8542.39.0001 | China |  | 1727-LSF0102DCHCT-ND | //media.digikey.com/Renders/Nexperia/1727~SOT765-1~DC~8.JPG
12 | TSW-105-07-F-T | Samtec Inc. | CONN HEADER VERT 15POS 2.54MM | 646 | In Stock |  | 3 | 3 | Bulk | SAM12316-ND | 19,62000 | kr 58,86 | 1 |  | SAM12316-ND | 11 | http://suddendocs.samtec.com/catalog_english/tsw_th.pdf |  | N/A |  | Active | ROHS3 Compliant | EAR99 | 8536.69.4040 | Malaysia |  | SAM12316-ND | //media.digikey.com/Renders/Samtec%20Renders/TSW-105-07-F-T.JPG
13 | 69145-210LF | Amphenol ICC (FCI) | CONN SHUNT .100" 10POS GOLD | 1 307 | In Stock |  | 6 | 6 | Bulk | 609-5642-ND | 12,01000 | kr 72,06 | 1 |  | 609-5642-ND | 8 | https://cdn.amphenol-cs.com/media/wysiwyg/files/drawing/69145.pdf |  | May apply on shipments to the U.S. |  | Active | RoHS Compliant | EAR99 | 8538.90.8180 | China |  | 609-5642-ND | //media.digikey.com/Photos/Amphenol%20Photos/69145-210LF.jpg
14 | 3020-10-0300-00 | CNC Tech | CONN HEADER SMD 10POS 2.54MM | 124 122 | In Stock |  | 6 | 6 | Tray | 1175-1621-ND | 7,11000 | kr 42,66 | 1 |  | 1175-1621-ND | 20 | https://www.cnctech.us/pdfs/3020-XX-0300-00%20(9T).pdf |  | N/A |  | Active | ROHS3 Compliant | EAR99 | 8536.69.4040 | Taiwan | https://www.cnctech.us/eurohs_new3.pdf | 1175-1621-ND | //media.digikey.com/Renders/CnC%20Tech%20Renders/3020-10-0300-00.jpg
15 | QPC02SXGN-RC | Sullins Connector Solutions | CONN JUMPER SHORTING .100" GOLD | 1 401 503 | In Stock |  | 25 | 25 | Bag | S9337-ND | 0,40840 | kr 10,21 | 1 |  | S9337-ND | 11 | https://s3.amazonaws.com/catalogspreads-pdf/PAGE128-129%20.100%20JUMPER.pdf |  | N/A |  | Active | ROHS3 Compliant | EAR99 | 8538.90.8180 | Taiwan | https://www.sullinscorp.com/wp-content/uploads/2021/08/Sullins-REACH-219-SVHC-Compliant-Statement.pdf|https://www.sullinscorp.com/wp-content/uploads/2019/03/Sullins-RoHS-Compliant-Statement.pdf | S9337-ND | //media.digikey.com/Photos/Sullins%20Photos/QPC02SXGN-RC.JPG
16 | 3220-20-0100-00 | CNC Tech | CONN HEADER VERT 20POS 1.27MM | 38 993 | In Stock |  | 3 | 3 | Tray | 1175-1636-ND | 11,31000 | kr 33,93 | 1 |  | 1175-1636-ND | 20 | http://www.cnctech.us/pdfs/3220-XX-0100-00_.pdf |  | N/A |  | Active | ROHS3 Compliant | EAR99 | 8536.69.4040 | Taiwan | https://www.cnctech.us/eurohs_new3.pdf | 1175-1636-ND | //media.digikey.com/Photos/CnC%20Tech/3220-20-0100-00.JPG
17 | 0878311411 | Molex | CONN HEADER VERT 14POS 2MM | 21 212 | In Stock |  | 3 | 3 | Tube | WM14809-ND | 24,02000 | kr 72,06 | 1 |  | WM14809-ND | 16 | https://www.molex.com/pdm_docs/ps/PS-87831-027.pdf |  | N/A |  | Active | ROHS3 Compliant | EAR99 | 8536.69.4040 | Malaysia | https://www.molex.com/datasheets/rohspdf/0878311411_rohs.pdf | WM14809-ND | //media.digikey.com/Photos/Molex/0878311411.jpg
18 | PUSB3AB2DFZ | Nexperia USA Inc. | TVS DIODE 4VWM 3.7VC DFN0603-3 | 28 069 | In Stock |  | 30 | 30 | Cut Tape (CT) | 1727-PUSB3AB2DFZCT-ND | 2,63480 | kr 79,04 | 1 |  | 1727-PUSB3AB2DFZCT-ND | 20 | https://assets.nexperia.com/documents/data-sheet/PUSB3AB2DF.pdf |  | May apply on shipments to the U.S. |  | Active | ROHS3 Compliant | EAR99 | 8541.10.0080 | China |  | 1727-PUSB3AB2DFZCT-ND | //media.digikey.com/Renders/Nexperia/DFN0603-3-(SOT8013).jpg

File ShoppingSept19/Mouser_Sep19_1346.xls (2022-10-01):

VGA CENTRIFUGE
Mouser No | Mfr. No | Manufacturer | Customer No | Description | RoHS | Lifecycle | Order Qty. | Price (NOK) | Ext.: (NOK)
485-3844 | 3844 | Adafruit |  | Input Devices 4x4 Matrix Keypad | In Transition |  | 3 | kr 61,05 | kr 183,15
595-TVP7002PZPR | TVP7002PZPR | Texas Instruments |  | Video ICs Tr 8/10B 165/110MSPS Video ADC | RoHS Compliant |  | 6 | kr 89,36 | kr 536,16
992-DB15F-VGA-TERM | DB15F-VGA-TERM | Gravitech |  | Terminal Block Interface Modules DB15 Female (VGA) Breakout Board | RoHS Compliant |  | 1 | kr 216,69 | kr 216,69
669-EC2620TTS-100T | EC2620TTS-100.000M TR | ABRACON |  | Standard Clock Oscillators 100MHz 3.3Vdc 20ppm -10C to +70C | RoHS Compliant |  | 3 | kr 31,40 | kr 94,20
595-THS8136IPHP | THS8136IPHP | Texas Instruments |  | Digital to Analog Converters - DAC Triple 10B 180MSPS Graphics & Video DAC | RoHS Compliant |  | 3 | kr 104,55 | kr 313,65

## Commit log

2022-09-10 write about DAC and ADC, we should get to ordering those
2022-09-11 write about VGA DDC, I2C and stuff
2022-09-11 try finding components for the PCB and development
2022-09-12 Started DRAM-FPGA schematic and outline of rest
    [centrifuge.kicad_pcb, centrifuge.kicad_sch, config_dram.kicad_sch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]
2022-09-16 Implemented DRAM connections
    [dram.kicad_sch, fpga_core.kicad_sch]
2022-09-17 Made initial pin map of SRAM-FPGA and possible routing
    [centrifuge.kicad_pcb, centrifuge.kicad_sch, config_dram.kicad_sch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]
2022-09-21 Completed majority of schematic, need to add decoupling but otherwise mostly ready
    [centrifuge.kicad_pcb, centrifuge.kicad_sch, config_dram.kicad_sch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]
2022-09-30 FPGA PCB design completed
    [centrifuge.kicad_pcb, centrifuge.kicad_sch, fpga_core.kicad_sch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]
2022-10-01 write about SRAM chip and timing, as well as add some SD card over SPI links
2022-10-01 add note about I2C voltage, and link to ADC
2022-10-01 add level shifters for I2C, H/V-SYNC and MCU clock to shopping list
2022-10-01 add some connectors to the shopping list
2022-10-01 change I2C level switch on shopping list
2022-10-01 replace all level switches with a single cheap one
2022-10-01 add some connectors, the config flash, and I2C mosfets to the shopping list
2022-10-01 finish main component shopping list
    [DigiKey_Sep19_1346.xlsx, Mouser_Sep19_1346.xls]
2022-10-01 work on MCU schematic
    [SD_card.kicad_sch, button_panel.kicad_sch, centrifuge_mcu.kicad_pcb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]
2022-10-01 make and pick footprints for almost everything
    [DigiKey_Sep19_1346.xlsx, Mouser_Sep19_1346.xls, SD_card.kicad_sch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]
2022-10-01 more footprints, add links to resistor and inductance purchase
    [SD_card.kicad_sch, button_panel.kicad_sch, centrifuge_mcu.kicad_sch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]
2022-10-01 last footprints, time to route (after final FPGA-board connectors)
    [SD_card.kicad_sch, button_panel.kicad_sch, centrifuge_mcu.kicad_sch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]
2022-10-01 start routing PCB for the MCU, starting with power
    [SD_card.kicad_sch, button_panel.kicad_sch, centrifuge_mcu.csv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]
2022-10-01 continue on power supply routing
    [SD_card.kicad_sch, centrifuge_mcu.kicad_pcb]
2022-10-01 slowly but surely decopling and connecting everything to the MCU
    [centrifuge_mcu.kicad_pcb, centrifuge_mcu.kicad_sch]
2022-10-01 hooking things up to the MCU, maybe we could even make the board a bit smaller
    [centrifuge_mcu.kicad_pcb]
2022-10-01 do all MCU I think I can before merging in FPGA PCB
    [centrifuge_mcu.kicad_pcb]
2022-10-01 rebase with FPGA pcb, trying to add it
    [centrifuge_mcu.kicad_pcb]
2022-10-02 connect everything in MCU pcb, connection time
    [centrifuge_mcu.kicad_pcb, centrifuge_mcu.kicad_sch, mcu.kicad_sch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]
2022-10-02 Draft merged PCB
    [SD_card.kicad_sch, button_panel.kicad_sch, centrifuge.kicad_sch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]
2022-10-02 Almost finished releasable version
    [centrifuge.kicad_pcb, centrifuge.kicad_sch, centrifuge_mcu.kicad_sch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]
2022-10-03 Board appears ok
    [SD_card.kicad_sch, button_panel.kicad_sch, centrifuge.kicad_sch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]
2022-10-03 fixed keypad hole sizes, and submitted
    [SD_card.kicad_sch, button_panel.kicad_sch, centrifuge.kicad_sch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]
2022-10-03 create new PSU routing for all 6 voltages
    [SD_card.kicad_sch, button_panel.kicad_sch, centrifuge.kicad_pcb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]
2022-10-03 Fixed missing footprints, added decoupling capacitors, adjusted board edges
    [SD_card.kicad_sch, button_panel.kicad_sch, centrifuge.kicad_sch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]
2022-10-03 Fixed up schematic names and page numbers
    [fpga_part.kicad_sch, mcu.kicad_sch]
2022-10-03 Improved PCB manufacturing tolerances
    [centrifuge.kicad_sch]
2022-10-04 remove digikey links to products that we already buy from mouser, add mouser link instead
    [SD_card.kicad_sch, button_panel.kicad_sch, centrifuge_mcu.kicad_sch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]
2022-10-05 fix elprint complaints, except intranet clearance, also widen some traces
    [centrifuge.kicad_sch, centrifuge_mcu.kicad_sch, fpga_part.kicad_sch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]
2022-10-05 more checks, also make silkscreen text for connectors
    [centrifuge.kicad_sch, fpga_part.kicad_sch, pwr_jtag.kicad_sch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]
2022-10-05 fix JTAG Vref, pullup on CS and remove SRAM_CS1p3
    [centrifuge.kicad_sch, config_sram.kicad_sch, pwr_jtag.kicad_sch]
2022-10-05 make some power traces thicker
2022-10-06 HANDIN: do final pcb trace niceness
2022-10-12 start on shopping list 2
    [centrifuge.ods]
2022-10-13 make final shopping list, added to Mouser and DigiKey lists. Also budget. Swaps out TVS diodes
    [budget.ods, centrifuge.kicad_sch, centrifuge.ods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]
2022-10-13 fix duplicate Cs, add extra ACD/DAC and breakout, and fix TVS schematic hidden pin
    [centrifuge.ods, pwr_jtag.kicad_sch, vga_interface.kicad_sch]
2022-10-13 export DigiKey and Mouser lists to excel. Add extra to DigiKey where cheaper
    [DigiKey_Oct13_1119.xlsx, Mouser_Oct13_1120.xls, budget.ods]
2022-10-18 add spreadsheet for actual choices of I2C resistors
    [resistor_choices.ods]
2022-10-22 change resistor values to have to 2k2, and also make I2C hopefully work
    [DigiKey_Oct13_1119.xlsx, button_panel.kicad_sch, centrifuge.kicad_sch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]
2022-10-28 change the names of some named wires in the schematic, to make numbering more consistent
    [centrifuge.kicad_sch, centrifuge_mcu.kicad_sch, fpga_part.kicad_sch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]
2022-10-28 add shopping list for last batch of missing capacitors
    [DigiKey_Oct24_LastCaps.xlsx]
2022-11-03 fix mismatch between VSYNC and HSYNC out, only needs a swap in constraints file as well
    [fpga_core.kicad_sch, fpga_part.kicad_sch]
2022-11-03 also reimport schematic into pcb, no differences
2022-11-09 fully commit to calling top VGA ADC2
    [ddc_eeprom.kicad_sch, fpga_core.kicad_sch, fpga_part.kicad_sch]
2022-11-12 add note about changes to VGA0's I2C stuff
    [vga_interface.kicad_sch]
